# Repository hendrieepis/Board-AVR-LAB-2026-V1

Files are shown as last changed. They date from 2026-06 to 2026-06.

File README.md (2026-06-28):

# 📋 Panduan Desain: Shield Arduino Mega 2560 — PENS Expansion Board V2.0

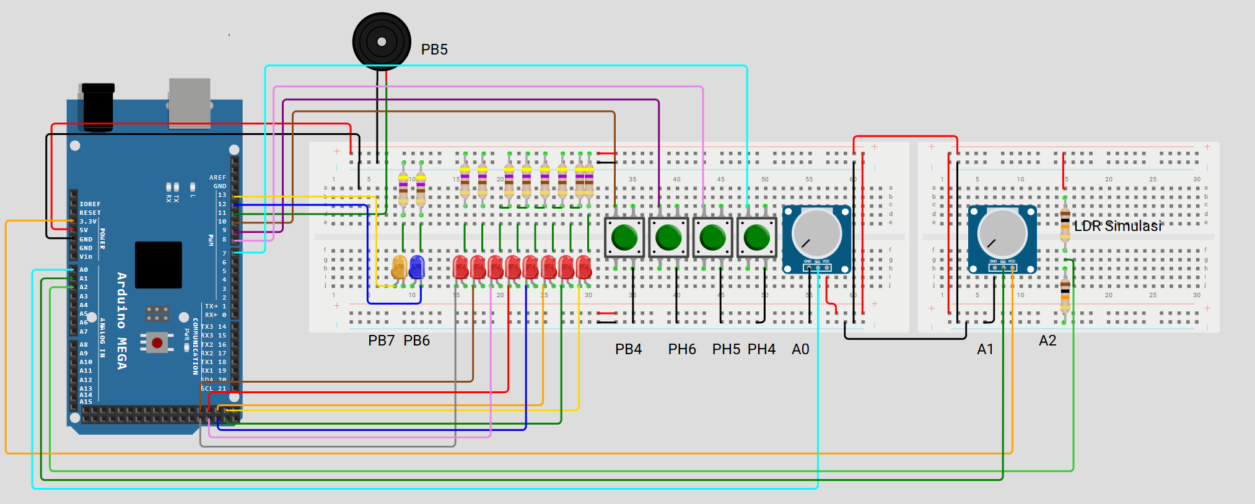
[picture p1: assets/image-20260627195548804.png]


---

## 📐 Spesifikasi Teknis

### 1. Dimensi & Form Factor

| Parameter | Nilai |
|---|---|
| Panjang | 101.6 mm / 4000 mil (exact Arduino Mega R3) |
| Lebar | 53.3 mm / 2098 mil (exact Arduino Mega R3) |
| Ketebalan PCB | 1.6 mm / 63 mil (FR4) |
| Lubang mounting | 4× (diameter 3.2 mm / 126 mil) |
| Jumlah layer | 2 (dua layer) |
| Konektor ke Mega | *Stackable female header* 2.54 mm / 100 mil |

### 2. Sumber Daya

- **Source:** Arduino Mega 5V rail saja (tidak ada *external power*)
- **Decoupling:** 4× 100 nF (0805) — distribusi dekat cluster MOSFET untuk menjaga stabilitas switching

### 3. Pin Assignment (WAJIB SAMA DENGAN WOKWI)

> ⚠️ **PENTING:** Pin *assignment* harus persis sama dengan simulator Wokwi PENS Elka. Jangan merubah *mapping* pin karena akan menyebabkan kode tidak kompatibel antara simulator dan *hardware* fisik.

#### 3.1. LED Array (8 LED Merah — PORTA)

| Arduino Pin | AVR Port | Device | Warna | Reference |
|---|---|---|---|---|
| D22 | PA0 | LED1 | Merah | D0 |
| D23 | PA1 | LED8 | Merah | D1 |
| D24 | PA2 | LED7 | Merah | D2 |
| D25 | PA3 | LED5 | Merah | D3 |
| D26 | PA4 | LED3 | Merah | D4 |
| D27 | PA5 | LED6 | Merah | D5 |
| D28 | PA6 | LED4 | Merah | D6 |
| D29 | PA7 | LED2 | Merah | D7 |

**Package:** LED SMD 0805 (`LED_SMD:LED_0805_2012Metric_Pad1.15x1.40mm_HandSolder`)

**Tata letak PCB:** Susun LED dalam satu baris dari PA0 di kiri hingga PA7 di kanan agar mahasiswa bisa membaca *pattern* `PORTA` secara visual.

#### 3.2. LED Indikator (2 LED)

| Arduino Pin | AVR Port | Device | Warna | Reference |
|---|---|---|---|---|
| D12 | PB6 | LED9 | Merah | DA1 |
| D13 | PB7 | LED10 | Hijau | DB1 |

**Package:** LED SMD 0805 (sama dengan LED array)

#### 3.3. Buzzer

| Arduino Pin | AVR Port | Device | Reference |
|---|---|---|---|
| D11 | PB5 | Buzzer (piezo/magnetic 5V) | BZ1 |

**Skema rangkaian:**

```
        +5V
         │
       ┌─┴─┐
     1 │ + │ BZ1
       │   │ Buzzer
     2 │   │
       └─┬─┘
         │
       ┌─┴─┐
       │R6 │ 1K
       └─┬─┘
         │ 3
   D11 1 ┤├─┐
    ●────┤  │ Q2
    │    ┤├─┘ BSS138
  ┌─┴─┐    │ 2
  │R5 │    │
  │1M │    │
  └─┬─┘    │
    │      │
   GND    GND
```

#### 3.4. Push Button (Active-LOW, 4 unit)

| Arduino Pin | AVR Port | Device | Reference |
|---|---|---|---|
| D10 | PB4 | BTN1 | SW1 |
| D9 | PH6 | BTN2 | SW2 |
| D8 | PH5 | BTN3 | SW3 |
| D7 | PH4 | BTN4 | SW4 |

**Skema rangkaian (debounce):**

```
   +5V
    │
  ┌─┴─┐
  │R13│ 10K
  └─┬─┘
    ●──── D7
  ┌─┴─┐
  │R14│ 1K
  └─┬─┘
    ●─────────┐
   o│         │
   SW4       ─┴─ C4
   SW_Push   ─┬─ 0.1uF
   o│         │
    ●─────────┘
    │
   GND
```

- **Package:** Tactile switch 6×6 mm THT (`Button_Switch_THT:SW_PUSH_6mm`)
- **Tinggi actuator:** Rekomendasi 7.3H (ergonomis untuk jari, tidak mudah rusak)
- Tombol aktif saat ditekan (menghubungkan pin ke GND)
- Menggunakan internal pull-up AVR (`INPUT_PULLUP` di kode) — tidak perlu resistor pull-up eksternal
- **Alasan pilih THT (bukan SMD):** Untuk praktikum mahasiswa, THT jauh lebih robust terhadap tekanan berulang dan perlakuan kasar. Jalur PCB tidak mudah rusak karena kaki pin masuk ke PTH (plated through-hole), bukan hanya solder di permukaan.

#### 3.5. Potensiometer & LDR (Input Analog)

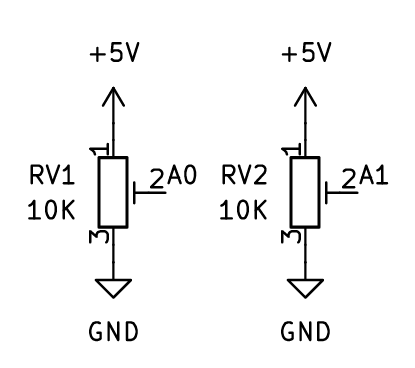
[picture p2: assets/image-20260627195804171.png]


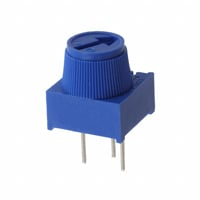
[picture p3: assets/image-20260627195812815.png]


| Arduino Pin | ADC Channel | Device | Reference | Tipe |
|---|---|---|---|---|
| A0 | ADC0 | POT1 | RV1 | Trimpot 10K |
| A1 | ADC1 | POT2 | RV2 | Trimpot 10K |
| A2 | ADC2 | LDR | R14 | GL5528 (5mm) |

**Package:**

- **Trimpot:** `Potentiometer_THT:Potentiometer_Bourns_3386P_Vertical` (Bourns 3386P 10K)
- **LDR:** `OptoDevice:R_LDR_5.1x4.3mm_P3.4mm_Vertical` (GL5528, pitch 3.4mm)

**Konfigurasi:**

- **Trimpot (RV1, RV2):** Voltage divider standar — Pin 1 ke +5V, Pin 3 ke GND, wiper (Pin 2) ke ADC
- **LDR (R14):** Voltage divider dengan resistor partner 10K (R_LDR ke +5V, R_10K ke GND, tap ke ADC)

---

## 🔌 Rangkaian Driver (MOSFET Isolation)

### Skema Driver LED (diulang untuk 8 LED PORTA + 2 LED indikator + Buzzer = 11 channel)

```
        +5V
         │
        ─┴─
        \ / D7
        ─┬─ LED
         │
       ┌─┴─┐
       │R32│ 1K
       └─┬─┘
         │ 3
  D29  1 ┤├─┐
   ●─────┤  │ Q12
   │     ┤├─┘ BSS138
 ┌─┴─┐     │ 2
 │R31│     │
 │1M │     │
 └─┬─┘     │
   │       │
  GND     GND
```

### Komponen per Channel LED

| # | Komponen | Nilai | Package | Fungsi |
|---|---|---|---|---|
| 1 | MOSFET | BSS138 | SOT-23 | Switch utama |
| 2 | Resistor pull-up | 10 kΩ | 0805 | Gate bias ke +5V |
| 3 | Resistor pull-down | 1 MΩ | 0805 | Cegah *flicker* saat pin INPUT |
| 4 | Resistor LED | 1 kΩ | 0805 | Pembatas arus LED (~3 mA) |
| 5 | LED | Merah/Hijau | 0805 | Indikator visual |

### Perilaku Driver

| Kondisi Pin Arduino | Gate MOSFET | LED |
|---|---|---|
| HIGH (5V) | HIGH | ON |
| LOW (0V) | LOW | OFF |
| INPUT (floating) | LOW (via R 1M) | OFF (tidak *flicker*) |

---

## 🔗 Antarmuka Komunikasi

### 1. Header I2C (JST PH 2.0, 4-pin)

**Reference:** J10 (atau salah satu dari J10, J11, J12)
**Footprint:** `Connector_JST:JST_PH_B4B-PH-K_1x04_P2.00mm_Vertical`

| Pin | Nama | Koneksi |
|---|---|---|
| 1 | GND | GND |
| 2 | VCC | +5V |
| 3 | SDA | Arduino pin 20 |
| 4 | SCL | Arduino pin 21 |

> **Catatan I2C pull-up:** ATmega2560 memiliki internal pull-up untuk SDA/SCL. Untuk modul I2C 5V standard (OLED, sensor), internal pull-up cukup. Jika menggunakan modul yang butuh pull-up eksternal, tambahkan resistor 4.7K di sisi modul.

### 2. Header SPI (JST PH 2.0, 6-pin)

**Reference:** J8 atau J9
**Footprint:** `Connector_JST:JST_PH_B6B-PH-K_1x06_P2.00mm_Vertical`

| Pin | Nama | Koneksi |
|---|---|---|
| 1 | GND | GND |
| 2 | VCC | +5V |
| 3 | MOSI | Arduino pin 51 |
| 4 | MISO | Arduino pin 50 |
| 5 | SCK | Arduino pin 52 |
| 6 | CS | Arduino pin 53 |

### 3. Header UART (JST PH 2.0, 4-pin)

**Reference:** J11 atau J12
**Footprint:** `Connector_JST:JST_PH_B4B-PH-K_1x04_P2.00mm_Vertical`

| Pin | Nama | Koneksi |
|---|---|---|
| 1 | GND | GND |
| 2 | VCC | +5V |
| 3 | TX1 | Arduino pin 18 (Serial1 TX) |
| 4 | RX1 | Arduino pin 19 (Serial1 RX) |

> Menggunakan **Serial1** (bukan Serial0) agar USB *debug* tetap tersedia untuk *Serial Monitor*.

**Praktik desain:**

- *Expose* semua pin yang digunakan di sisi atas dan bawah *board*
- *Silkscreen* dual label: "D22 / PA0", "A0 / ADC0", dst.
- Termasuk multiple *access point* untuk +5V dan GND

---

## 🎨 Prioritas Layout PCB

1. LED array disusun horizontal dari kiri ke kanan: PA0 → PA7
2. Push button dikelompokkan (4 tombol dalam satu baris)
3. Input analog dikelompokkan (2 trimpot + 1 LDR dalam satu area)
4. Connector JST di tepi *board* untuk akses kabel yang mudah
5. Silkscreen dual label (Arduino pin + AVR port) pada setiap pin *breakout*
6. Component reference (R1, C1, Q1, dll.) terlihat setelah *assembly*
7. **LDR penempatan:** Jauhkan minimal 20mm dari LED indikator untuk menghindari cross-talk cahaya

---

## 🏭 Spesifikasi PCB & Manufacturing

### Spesifikasi Fisik

| Parameter | Nilai |
|---|---|
| Layer | 2 |
| Material | FR4 1.6 mm |
| Copper weight | 1 oz (35 µm) |
| *Soldermask* | Hitam atau ungu |
| *Silkscreen* | Putih |
| Surface finish | HASL Lead-free (gratis) |
| *Ground plane* | *Bottom layer* |
| *Top layer* | Signal + komponen |

### Layer Strategy

```
TOP layer:    Body semua komponen (SMD & THT)
              SMD solder pads di sini
              Signal trace + VCC

BOTTOM layer: Solder pad untuk pin THT (saja)
              Ground plane solid
              Minimize signal trace
```

**Prinsip desain:**

- ❌ Bottom layer **JANGAN** dijadikan VCC plane
- ✅ Bottom layer = **Ground plane solid** (lebih baik untuk EMI, signal integrity, dan ADC accuracy)
- ✅ VCC sebagai **trace tebal** di top layer (0.5 mm / 20 mil)
- ✅ Decoupling capacitor (100 nF) dekat dengan cluster MOSFET
- ✅ Stitching via di area ground pour (1 via per 1–2 cm²) untuk low-impedance ground

### Bonus

**Bonus (optional, nilai plus):** Tambahkan **logo PENS** dan/atau **tulisan "Prodi Elka"** di area kosong **Bottom Silkscreen (B.Silkscreen)** sebagai identitas board. Bisa dalam bentuk:

- Logo PENS (import image ke KiCad)
- Tulisan "Prodi Elka - PENS" dengan KiCad text tool
- Atau kombinasi keduanya

Contoh:

```
┌────────────────────────────────────┐
│                                    │
│           [Logo PENS]              │
│                                    │
│        PENS EXPANSION BOARD        │
│           V2.0 (2026)              │
│      Prodi Teknik Elektronika      │
│                                    │
└────────────────────────────────────┘
```

---

## 📏 Design Rules untuk JLCPCB (Safe Settings)

> ⚠️ **PENTING:** Design rules di bawah ini adalah **recommended safe values** — lebih besar dari JLCPCB minimum — untuk margin terhadap manufacturing tolerance. Jangan mendesain persis di JLCPCB minimum karena risiko reject atau defect tinggi.

### Design Rules Cheatsheet

```
┌──────────────────────────────────────────────────────┐
│  PCB DESIGN RULES (JLCPCB Safe Settings)             │
├──────────────────────────────────────────────────────┤
│                                                      │
│  TRACK WIDTH:                                        │
│    Signal:  0.25 mm  (10 mil)                        │
│    Power:   0.5  mm  (20 mil)                        │
│                                                      │
│  CLEARANCE:                                          │
│    Track – track:  0.2 mm  (8 mil)                   │
│    Track – pad:    0.2 mm  (8 mil)                   │
│    Track – edge:   0.3 mm  (12 mil)                  │
│                                                      │
│  VIA:                                                │
│    Signal:  0.3 / 0.6 mm  (12 / 24 mil)              │
│    Power:   0.4 / 0.8 mm  (16 / 32 mil)              │
│                                                      │
│  HOLE (THT):                                         │
│    Min drill:     0.3 mm  (12 mil) – JLCPCB limit    │
│    Typical pin:   0.6 – 1.0 mm  (24 – 39 mil)        │
│    Annular ring:  0.15 mm  (6 mil) per side          │
│                                                      │
│  BOARD EDGE:                                         │
│    Copper – edge:     0.3 mm  (12 mil)               │
│    Component – edge:  1.0 mm  (39 mil)               │
│    Mounting – edge:   2.0 mm  (79 mil)               │
│                                                      │
│  SILKSCREEN:                                         │
│    Line width:   0.15 mm  (6 mil)                    │
│    Text height:  1.0 mm  (39 mil)                    │
│    Pad clear:    0.15 mm  (6 mil)                    │
│                                                      │
│  UNIT CONVERSION:                                    │
│    1 mil = 0.0254 mm                                 │
│    1 mm  = 39.37 mil                                 │
│                                                      │
└──────────────────────────────────────────────────────┘
```

> 💡 **Tip praktis:** Biasakan mikir dalam mil untuk track width dan mm untuk board dimension — convention yang umum di komunitas PCB global. KiCad support keduanya, switch via View → Units atau shortcut Ctrl+U.

**Current capacity:** Trace 0.5 mm (20 mil) pada 1 oz copper = ~1.6 A (10°C rise). Estimasi beban project ini ≈ 300 mA (10 LED × 3 mA + buzzer 50 mA + modul external 200 mA), jadi margin ~5× — sangat aman.

### Clearance Komponen

**Clearance** = jarak minimum antara dua komponen di PCB, diukur dari body/pad komponen satu ke body/pad komponen sebelahnya.

```
[Komponen A] ←─── clearance ───→ [Komponen B]
   body                              body
```

| Antar Komponen | Recommended | Alasan |
|---|---|---|
| SMD 0805 – SMD 0805 | **0.5 mm (20 mil)** | Akses solder iron |
| BSS138 (SOT-23) – neighbor | **1.0 mm (39 mil)** | Akses untuk rework |
| LED 0805 – LED 0805 (array PORTA) | **1.0 mm (39 mil)** | Visual separation, tidak overlap cahaya |
| Tactile switch (THT) – neighbor | **3 mm (118 mil)** | Space untuk jari menekan |
| Trimpot 3386P – neighbor | **2 mm (79 mil)** | Akses obeng untuk adjust |
| **LDR – LED indikator** | **20–30 mm (787–1181 mil)** | Hindari cross-talk cahaya ke LDR |
| JST PH – tepi PCB | **5 mm (197 mil)** | Clearance kabel saat dicolok |

> Ini berbeda dengan trace clearance (jarak antar jalur tembaga). Clearance komponen lebih ke urusan fisik/mekanis, sedangkan trace clearance urusan elektris.

### Cara Set di KiCad

1. PCB Editor → **File → Board Setup**
2. Tab **Design Rules → Constraints** → input nilai Global Constraints
3. Tab **Design Rules → Net Classes** → tambahkan class "Power", assign net VCC dan GND
4. Save

**Verifikasi sebelum export:** Inspect → **Design Rules Checker (DRC)** → target **zero error**, warning silkscreen diperiksa manual.

---

## ✅ Checklist Sebelum Submit Gerber

### Phase 1: KiCad DRC

- [ ] DRC run dengan zero error
- [ ] Warning silkscreen sudah direview (silkscreen overlap pad akan auto-remove oleh JLCPCB)
- [ ] Tidak ada unconnected net

### Phase 2: Visual Review

- [ ] **3D View** (Alt+3) — semua komponen muncul & positioned benar
- [ ] **Ground plane** di bottom layer solid, tidak split oleh signal
- [ ] **Stitching via** di ground pour, kerapatan 1 per 1–2 cm²
- [ ] **Decoupling cap** (100 nF) dekat dengan cluster MOSFET
- [ ] **Silkscreen** label Arduino pin + AVR port readable
- [ ] **Reference designator** (R1, Q1, dll.) visible setelah assembly

### Phase 3: Mechanical Fit

- [ ] **Board outline** (Edge.Cuts) closed polygon, 101.6 × 53.3 mm
- [ ] **4 mounting hole** di lokasi exact Arduino Mega R3
- [ ] **Stackable pin header** align dengan Arduino Mega socket
- [ ] **Clearance barrel jack** + **USB connector** Mega
- [ ] Tinggi komponen < 15 mm (agar shield bisa di-stack)

### Phase 4: Print 1:1 Test

- [ ] Print PDF top + bottom layer 1:1 di kertas
- [ ] Verifikasi skala dengan penggaris
- [ ] Taruh komponen fisik di atas print
- [ ] Footprint match pad, orientasi benar
- [ ] Komponen THT tidak bentrok dengan komponen SMD sekitar

### Phase 5: Gerber Export & Review

- [ ] File → **Fabrication Outputs → Gerbers** → export semua layer
- [ ] **Generate drill files** (.drl) — centang!
- [ ] Upload zip ke **JLCPCB Gerber Viewer** (online)
- [ ] Visual inspection setiap layer (top copper, bottom copper, silkscreen, drill)
- [ ] Verifikasi board size di viewer

### Common Rejection Reasons dari JLCPCB

| Masalah | Solusi |
|---|---|
| Trace terlalu kecil (<6 mil) | Set min track width 0.2 mm (8 mil) |
| Hole <0.3 mm (12 mil) | Min drill 0.3 mm (12 mil) untuk via, 0.6 mm (24 mil) untuk pin THT |
| Trace terlalu dekat ke tepi PCB | Edge clearance minimum 0.3 mm (12 mil) — safer 0.5 mm (20 mil) |
| Silkscreen overlap pad | Kasih gap 0.15 mm (6 mil) (atau ikhlaskan auto-remove) |
| Missing drill file | Export .drl terpisah saat Gerber export |
| Board outline tidak closed | Edge.Cuts harus single closed polygon |

---

## 💪 Pro Tips dari Pengalaman Fabrikasi

### 1. Mulai DRC Lenient, Tighten Later

Saat awal routing, set DRC minimum (0.127 mm) biar KiCad router fleksibel. Setelah semua trace selesai, **tighten DRC** ke nilai recommended (0.2 mm) lalu re-run DRC. Fix error yang muncul satu per satu.

### 2. Jangan Mepet Manufacturing Minimum

JLCPCB minimum 0.127 mm, tapi desain di 0.2 mm. Manufacturing punya tolerance ±0.05 mm, kalau mepet minimum → kena tolerance minus → fail. Selalu kasih margin.

### 3. Test Points untuk Debugging

Tambahkan **test points** (pad TH 1 mm diameter) di signal kritikal untuk kemudahan debugging pasca-assembly:

| Signal | Lokasi Recommended |
|---|---|
| VCC 5V | Dekat power input header |
| GND | Multiple (minimum 3 lokasi di PCB) |
| Analog A0–A2 | Dekat trimpot/LDR |
| UART TX/RX | Dekat JST PH UART |
| SPI bus | Dekat JST PH SPI |
| Gate MOSFET | 1–2 channel sebagai sample (untuk scope) |

**Footprint:** `TestPoint:TestPoint_Pad_D1.5mm` atau `TestPoint_THTPad_1.0x1.0mm_Drill0.5mm`

### 4. Print 1:1 Manual Check

Sebelum klik "Submit" di JLCPCB:

1. Export PDF top + bottom layer dengan scale **1:1**
2. Print di kertas, verifikasi skala dengan penggaris (pastikan PCB 101.6 mm sesuai penggaris)
3. Taruh komponen fisik di atas cetakan
4. Cek alignment footprint, clearance, orientasi
5. Simulasi: tekan tombol, putar trimpot, colok JST — apakah ada yang bentrok?

**10 menit manual check = save $10 wasted PCB + 2 minggu waiting.**

### 5. Save Gerber sebagai "Release"

Setelah submit, **tag Gerber file** dengan versi (misal `ExpansionBoard-V1.0-Gerber.zip`) dan commit ke Git. Kalau nanti ada revisi, bisa compare version history.

---

## 📚 Referensi & Resources

### Datasheet Komponen Kritis

- BSS138 MOSFET Datasheet
- ATmega2560 (Arduino Mega) Datasheet
- JST PH Series Datasheet
- Bourns 3386P Potentiometer Datasheet
- LDR GL5528 Datasheet

### Tutorial & Learning

- KiCad Getting Started
- JLCPCB Ordering Guide

### Inspirasi Desain

- Cytron Maker Pi Pico Schematic — referensi MOSFET isolation topology
- Arduino Mega R3 Schematic

### Library KiCad

- SnapEDA Arduino Mega 2560 Rev3

## Release

VersiA

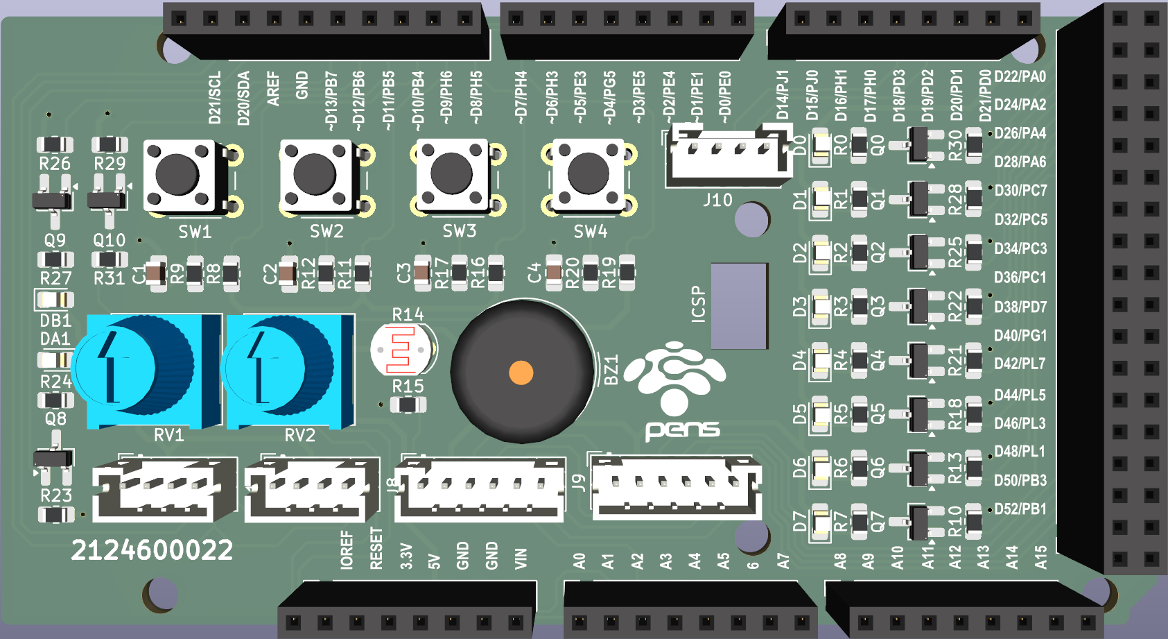
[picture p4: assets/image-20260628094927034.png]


- KICAD ->    [versiA](versiA) 

- Gerver->  https://github.com/hendrieepis/Board-AVR-LAB-2026-V1/blob/master/versiA/gerber.zip

VersiB

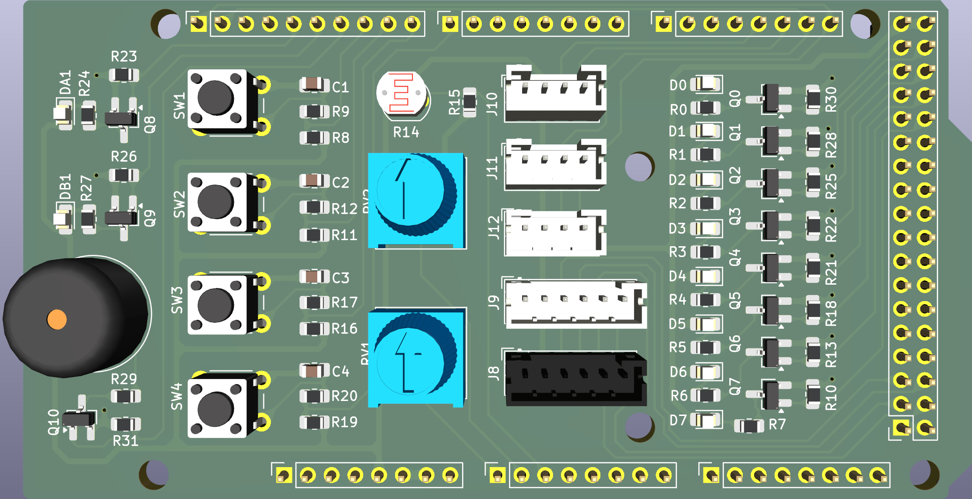
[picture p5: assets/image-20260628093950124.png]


- KICAD ->     [VersiB](VersiB) 

- Gerber ->   https://github.com/hendrieepis/Board-AVR-LAB-2026-V1/blob/master/VersiB/gerber.zip

Pcloud

- https://e.pcloud.link/publink/show?code=kZzxKcZidlPBQnEcohYrJGMhkQTauFlQ4nX

## Test hardware

-  [test-hardware](test-hardware)

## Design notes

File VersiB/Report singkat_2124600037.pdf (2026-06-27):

NAMA : MUHAHAMMAD BAGUS EKA WIJAYA KELAS: 2 D4 EB
NRP :2124600037

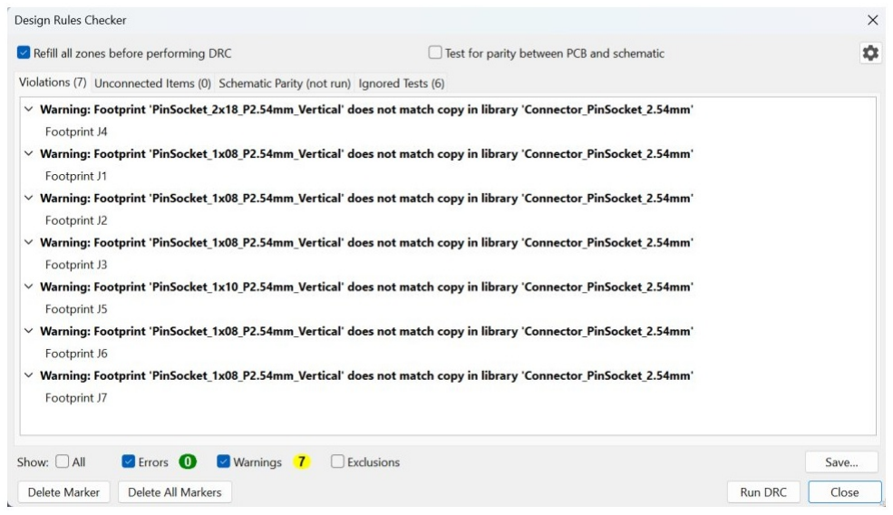
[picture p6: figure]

Sering masuk Properties saat melakukan routing, solusinya routing pelan pelan . ·Pertama kali menggunakan Kicad jadi bingung untuk letak setting dan short cut fiturnya .Solusinya di bantu dengan Al dan YouTube.
·Jumlah Via yang di gunakan 11 Via.

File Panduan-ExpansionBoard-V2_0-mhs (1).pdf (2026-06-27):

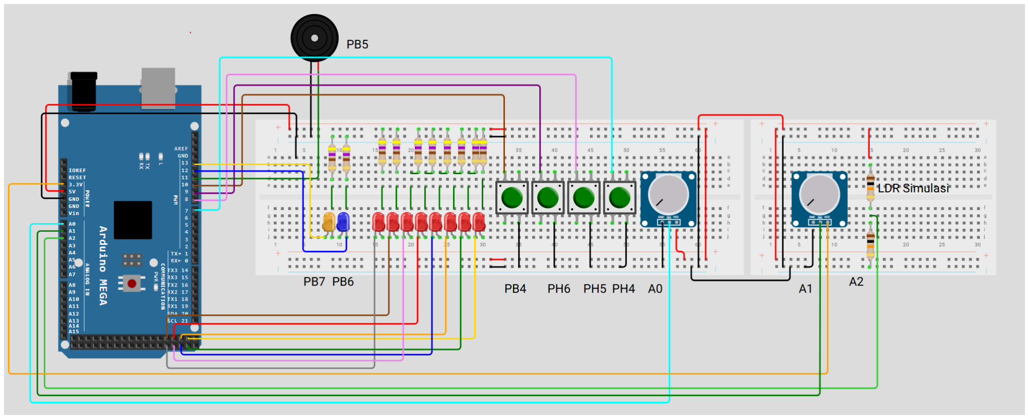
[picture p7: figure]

Parameter | Nilai
Panjang | 101.6 mm / 4000 mil (exact Arduino Mega R3)
Lebar | 53.3 mm / 2098 mil (exact Arduino Mega R3)
Ketebalan PCB | 1.6 mm / 63 mil (FR4)
Lubang mounting | 4× (diameter 3.2 mm / 126 mil)
Jumlah layer | 2 (dua layer)
Konektor ke Mega | Stackable female header 2.54 mm / 100 mil
Arduino Pin | AVR Port | Device | Warna | Reference
D22 | PA0 | LED1 | Merah | D0

# 📋 Panduan Desain: Shield Arduino Mega 2560 — PENS Expansion Board V2.0

# 📐 Spesifikasi Teknis

## 1. Dimensi & Form Factor

## 2. Sumber Daya

Source: Arduino Mega 5V rail saja (tidak ada external power)
Decoupling: 4× 100 nF (0805) — distribusi dekat cluster MOSFET untuk menjaga stabilitas switching

## 3. Pin Assignment (WAJIB SAMA DENGAN WOKWI)

⚠️ PENTING: Pin assignment harus persis sama dengan simulator Wokwi PENS Elka. Jangan merubah mapping pin karena akan menyebabkan kode tidak kompatibel antara simulator dan hardware fisik.

### 3.1. LED Array (8 LED Merah — PORTA)

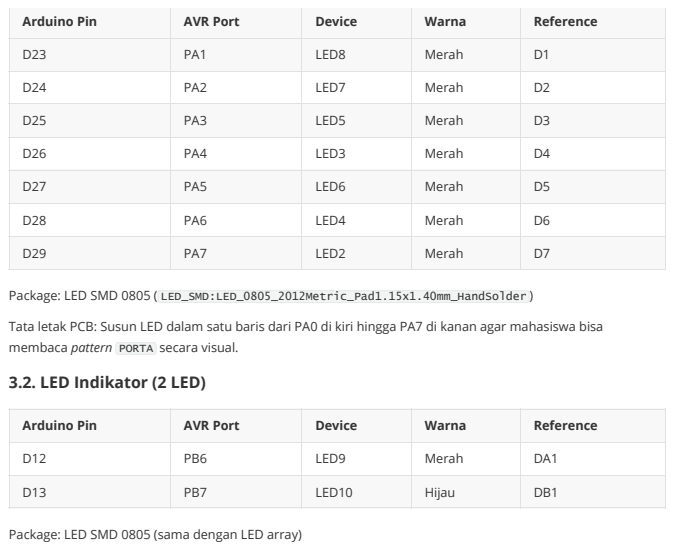
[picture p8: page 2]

Arduino Pin | AVR Port | Device | Warna | Reference

D23 | PA1 | LED8 | Merah | D1

D24 | PA2 | LED7 | Merah | D2

D25 | PA3 | LED5 | Merah | D3

D26 | PA4 | LED3 | Merah | D4

D27 | PA5 | LED6 | Merah | D5

D28 | PA6 | LED4 | Merah | D6

D29 | PA7 | LED2 | Merah | D7

Package: LED SMD 0805 ( LED_SMD:LED_0805_2012Metric_Pad1.15x1.40mm_HandSolder )
Tata letak PCB: Susun LED dalam satu baris dari PA0 di kiri hingga PA7 di kanan agar mahasiswa bisa
membaca pattern PORTA secara visual.
3.2. LED Indikator (2 LED)

D12 | PB6 | LED9 | Merah | DA1

D13 | PB7 | LED10 | Hijau | DB1

Package: LED SMD 0805 (sama dengan LED array)

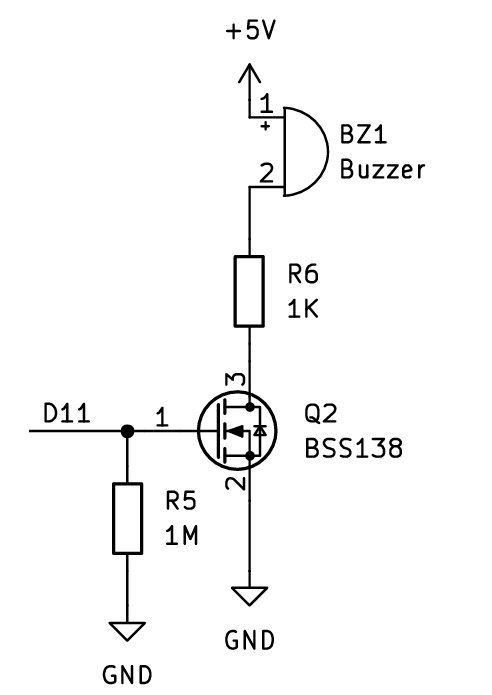
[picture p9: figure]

Arduino Pin | AVR Port | Device | Reference
D11 | PB5 | Buzzer (piezo/magnetic 5V) | BZ1

### 3.3. Buzzer

### 3.4. Push Button (Active-LOW, 4 unit)

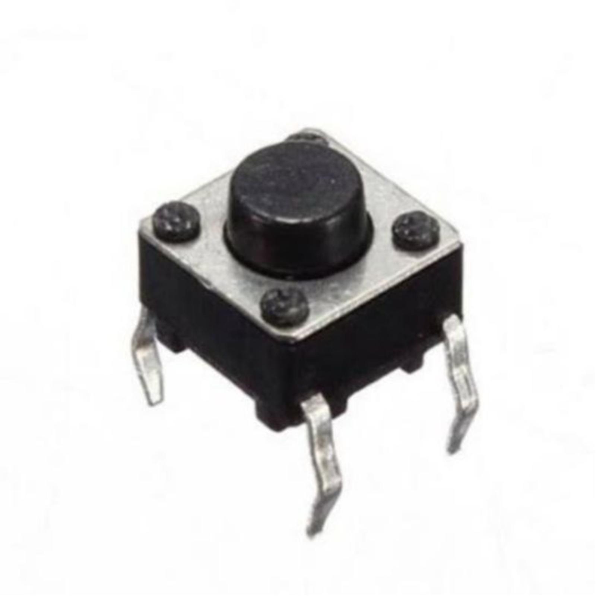
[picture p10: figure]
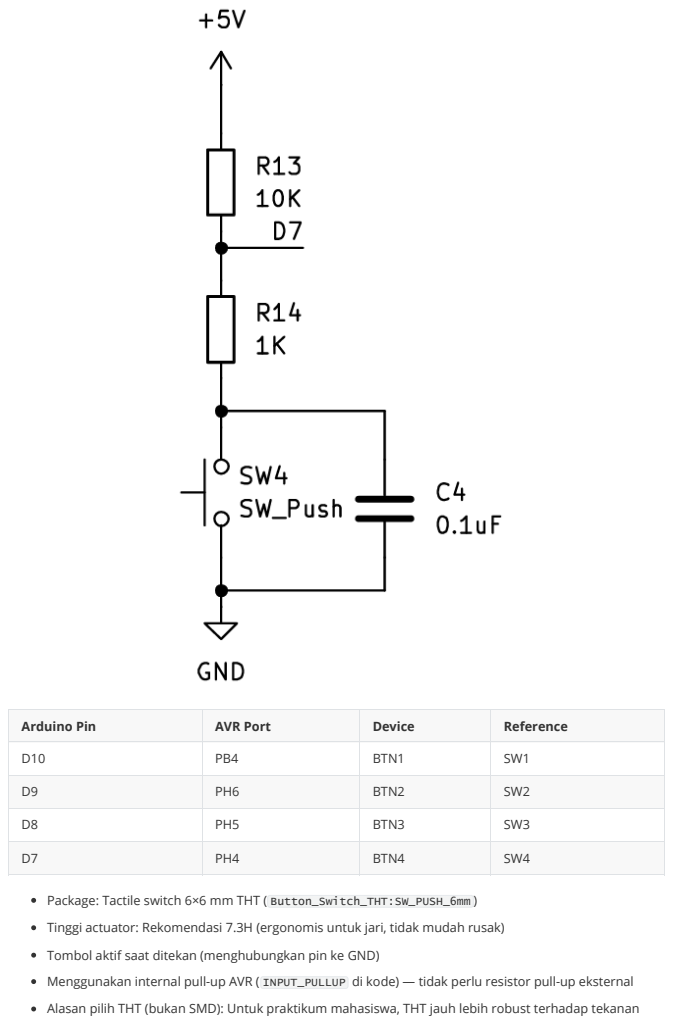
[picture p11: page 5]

Arduino Pin | AVR Port | Device | Reference

D10 | PB4 | BTN1 | SW1

D9 | PH6 | BTN2 | SW2

D8 | PH5 | BTN3 | SW3

D7 | PH4 | BTN4 | SW4

Package: Tactile switch 6×6 mm THT ( Button_Switch_THT:SW_PUSH_6mm )
Tinggi actuator: Rekomendasi 7.3H (ergonomis untuk jari, tidak mudah rusak)
Tombol aktif saat ditekan (menghubungkan pin ke GND)
Menggunakan internal pull-up AVR ( INPUT_PULLUP di kode) — tidak perlu resistor pull-up eksternal
Alasan pilih THT (bukan SMD): Untuk praktikum mahasiswa, THT jauh lebih robust terhadap tekanan

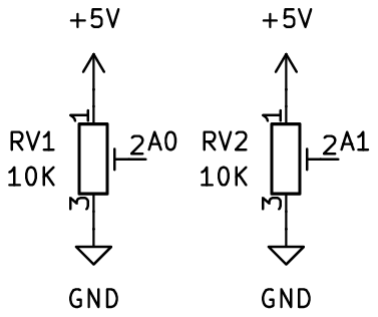
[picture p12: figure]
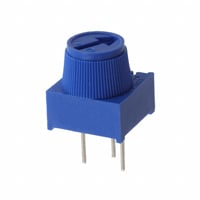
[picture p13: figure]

Arduino Pin | ADC Channel | Device | Reference | Tipe
A0 | ADC0 | POT1 | RV1 | Trimpot 10K
A1 | ADC1 | POT2 | RV2 | Trimpot 10K
A2 | ADC2 | LDR | R14 | GL5528 (5mm)

berulang dan perlakuan kasar. Jalur PCB tidak mudah rusak karena kaki pin masuk ke PTH (plated through-hole), bukan hanya solder di permukaan

### 3.5. Potensiometer & LDR (Input Analog)

Package:

Trimpot: Potentiometer_THT:Potentiometer_Bourns_3386P_Vertical (Bourns 3386P 10K)

LDR: OptoDevice:R_LDR_5.1x4.3mm_P3.4mm_Vertical (GL5528, pitch 3.4mm)

Konfigurasi:

Trimpot (RV1, RV2): Voltage divider standar — Pin 1 ke +5V, Pin 3 ke GND, wiper (Pin 2) ke ADC LDR (R14): Voltage divider dengan resistor partner 10K (R_LDR ke +5V, R_10K ke GND, tap ke ADC)

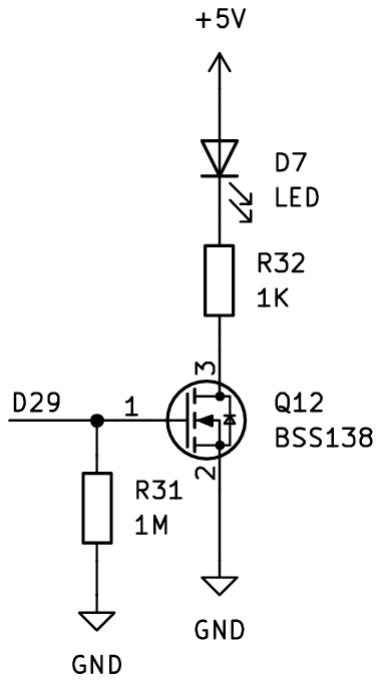
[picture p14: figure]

# | Komponen | Nilai | Package | Fungsi

1 | MOSFET | BSS138 | SOT-23 | Switch utama
2 | Resistor pull-up | 10 kΩ | 0805 | Gate bias ke +5V
3 | Resistor pull-down | 1 MΩ | 0805 | Cegah flicker saat pin INPUT
4 | Resistor LED | 1 kΩ | 0805 | Pembatas arus LED (~3 mA)
5 | LED | Merah/Hijau | 0805 | Indikator visual

# 🔌 Rangkaian Driver (MOSFET Isolation)

## Skema Driver LED (diulang untuk 8 LED PORTA + 2 LED indikator + Buzzer = 11 channel)

## Komponen per Channel LED

Kondisi Pin Arduino | Gate MOSFET | LED
HIGH (5V) | HIGH | ON
LOW (0V) | LOW | OFF
INPUT (floating) | LOW (via R 1M) | OFF (tidak flicker)
Pin | Nama | Koneksi
1 | GND | GND
2 | VCC | +5V
3 | SDA | Arduino pin 20
4 | SCL | Arduino pin 21
Pin | Nama | Koneksi
1 | GND | GND
2 | VCC | +5V
3 | MOSI | Arduino pin 51
4 | MISO | Arduino pin 50
5 | SCK | Arduino pin 52
6 | CS | Arduino pin 53

## Perilaku Driver

# 🔗 Antarmuka Komunikasi

1. Header I2C (JST PH 2.0, 4-pin)

Reference: J10 (atau salah satu dari J10, J11, J12)

Footprint: Connector_JST:JST_PH_B4B-PH-K_1x04_P2.00mm_Vertical

Catatan I2C pull-up: ATmega2560 memiliki internal pull-up untuk SDA/SCL. Untuk modul I2C 5V standard (OLED, sensor), internal pull-up cukup. Jika menggunakan modul yang butuh pull-up eksternal, tambahkan resistor 4.7K di sisi modul.

## 2. Header SPI (JST PH 2.0, 6-pin)

Reference: J8 atau J9
Footprint: Connector_JST:JST_PH_B6B-PH-K_1x06_P2.00mm_Vertical

Pin | Nama | Koneksi
1 | GND | GND
2 | VCC | +5V
3 | TX1 | Arduino pin 18 (Serial1 TX)
4 | RX1 | Arduino pin 19 (Serial1 RX)
Parameter | Nilai
Layer | 2
Material | FR4 1.6 mm
Copper weight | 1 oz (35 µm)
Soldermask | Hitam atau ungu
Silkscreen | Putih
Surface finish | HASL Lead-free (gratis)

## 3. Header UART (JST PH 2.0, 4-pin)

Reference: J11 atau J12

Footprint: Connector_JST:JST_PH_B4B-PH-K_1x04_P2.00mm_Vertical

Menggunakan Serial1 (bukan Serial0) agar USB debug tetap tersedia untuk Serial Monitor. Praktik desain:

Expose semua pin yang digunakan di sisi atas dan bawah board
Silkscreen dual label: "D22 / PA0", "A0 / ADC0", dst.
Termasuk multiple access point untuk +5V dan GND

# 🎨 Prioritas Layout PCB

1. LED array disusun horizontal dari kiri ke kanan: PA0 → PA7
2. Push button dikelompokkan (4 tombol dalam satu baris)
3. Input analog dikelompokkan (2 trimpot + 1 LDR dalam satu area)
4. Connector JST di tepi board untuk akses kabel yang mudah
5. Silkscreen dual label (Arduino pin + AVR port) pada setiap pin breakout
6. Component reference (R1, C1, Q1, dll.) terlihat setelah assembly
7. LDR penempatan: Jauhkan minimal 20mm dari LED indikator untuk menghindari cross-talk cahaya

# 🏭 Spesifikasi PCB & Manufacturing

## Spesifikasi Fisik

Parameter | Nilai
Ground plane | Bottom layer
Top layer | Signal + komponen

## Layer Strategy

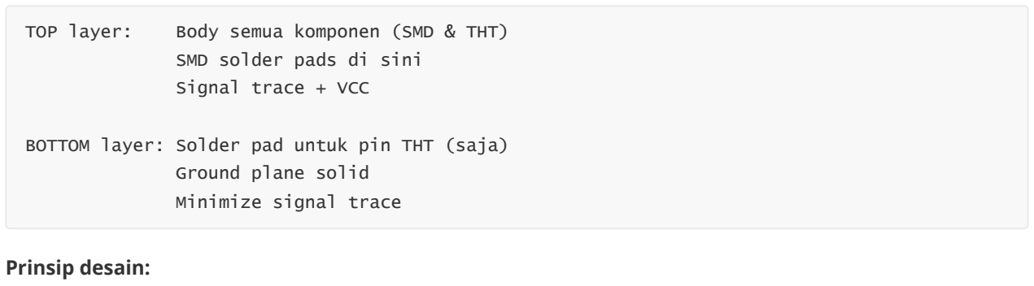
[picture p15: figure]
Prinsip desain:; SMD solder pads di sini; Signal trace + VCC; Ground plane solid; Minimize signal trace

❌ Bottom layer JANGAN dijadikan VCC plane
✅ Bottom layer = Ground plane solid (lebih baik untuk EMI, signal integrity, dan ADC accuracy) ✅ VCC sebagai trace tebal di top layer (0.5 mm / 20 mil)
✅ Decoupling capacitor (100 nF) dekat dengan cluster MOSFET
✅ Stitching via di area ground pour (1 via per 1–2 cm²) untuk low-impedance ground

## Bonus

Bonus (optional, nilai plus): - Tambahkan logo PENS dan/atau tulisan "Prodi Elka" di area kosong Bottom Silkscreen (B.Silkscreen) sebagai identitas board. Bisa dalam bentuk: - Logo PENS (import image ke KiCad) - Tulisan "Prodi Elka - PENS" dengan KiCad text tool - Atau kombinasi keduanya. Contoh

# 📏 Design Rules untuk JLCPCB (Safe Settings)

⚠️ PENTING: Design rules di bawah ini adalah recommended safe values — lebih besar dari JLCPCB minimum — untuk margin terhadap manufacturing tolerance. Jangan mendesain persis di JLCPCB minimum karena risiko reject atau defect tinggi.

TOP layer: Body semua komponen (SMD & THT)

BOTTOM layer: Solder pad untuk pin THT (saja)

┌────────────────────────────────────┐
│ | | │
│ | [Logo PENS] | │
│ | | │
│ | PENS EXPANSION BOARD | │
│ | V2.0 (2026) | │
│ | Prodi Teknik Elektronika | │
│ | | │
└────────────────────────────────────┘

## Design Rules Cheatsheet

💡 Tip praktis: Biasakan mikir dalam mil untuk track width dan mm untuk board dimension — convention yang umum di komunitas PCB global. KiCad support keduanya, switch via View → Units atau shortcut Ctrl+U.

Current capacity: Trace 0.5 mm (20 mil) pada 1 oz copper = ~1.6 A (10°C rise). Estimasi beban project ini ≈ 300 mA (10 LED × 3 mA + buzzer 50 mA + modul external 200 mA), jadi margin ~5× — sangat aman.

## Clearance Komponen

Clearance = jarak minimum antara dua komponen di PCB, diukur dari body/pad komponen satu ke body/pad komponen sebelahnya.

┌──────────────────────────────────────────────────────┐
│ PCB DESIGN RULES (JLCPCB Safe Settings) | │
├──────────────────────────────────────────────────────┤
│ | | | | | │
│ TRACK WIDTH: | │
│ | Signal: | 0.25 mm | (10 mil) | │
│ | Power: | 0.5 | mm | (20 mil) | │
│ | | | | | │
│ CLEARANCE: | │
│ | Track – track: | 0.2 mm | (8 mil) | │
│ | Track – pad: | 0.2 mm | (8 mil) | │
│ | Track – edge: | 0.3 mm | (12 mil) | │
│ | | | | | │
│ VIA: | │
│ | Signal: | 0.3 / 0.6 mm | (12 / 24 mil) | │
│ | Power: | 0.4 / 0.8 mm | (16 / 32 mil) | │
│ | | | | | │
│ HOLE (THT): | │
│ | Min drill: | 0.3 mm | (12 mil) — JLCPCB limit | │
│ | Typical pin: | 0.6 – 1.0 mm | (24 – 39 mil) | │
│ | Annular ring: | 0.15 mm | (6 mil) per side | │
│ | | | | | │
│ BOARD EDGE: | │
│ | Copper – edge: | 0.3 mm | (12 mil) | │
│ | Component – edge: | 1.0 mm | (39 mil) | │
│ | Mounting – edge: | 2.0 mm | (79 mil) | │
│ | | | | | │
│ SILKSCREEN: | │
│ | Line width: | 0.15 mm | (6 mil) | │
│ | Text height: | 1.0 mm | (39 mil) | │
│ | Pad clear: | 0.15 mm | (6 mil) | │
│ | | | | | │
│ UNIT CONVERSION: | │
│ | 1 mil = 0.0254 mm | │
│ | 1 mm | = 39.37 mil | │
│ | | | | | │
└──────────────────────────────────────────────────────┘
[Komponen A] | ←─── clearance ───→ | [Komponen B]
body | | body

Antar Komponen | Recommended | Alasan
SMD 0805 – SMD 0805 | 0.5 mm (20 mil) | Akses solder iron
BSS138 (SOT-23) – neighbor | 1.0 mm (39 mil) | Akses untuk rework
LED 0805 – LED 0805 (array PORTA) | 1.0 mm (39 mil) | Visual separation, tidak overlap cahaya
Tactile switch (THT) – neighbor | 3 mm (118 mil) | Space untuk jari menekan
Trimpot 3386P – neighbor | 2 mm (79 mil) | Akses obeng untuk adjust
LDR – LED indikator | 20–30 mm (787–1181 mil) | Hindari cross-talk cahaya ke LDR
JST PH – tepi PCB | 5 mm (197 mil) | Clearance kabel saat dicolok

Ini berbeda dengan trace clearance (jarak antar jalur tembaga). Clearance komponen lebih ke urusan fisik/mekanis, sedangkan trace clearance urusan elektris.

## Cara Set di KiCad

1. PCB Editor → File → Board Setup
2. Tab Design Rules → Constraints → input nilai Global Constraints
3. Tab Design Rules → Net Classes → tambahkan class "Power", assign net VCC dan GND
4. Save
Verifikasi sebelum export: Inspect → Design Rules Checker (DRC) → target zero error, warning silkscreen diperiksa manual.

## Checklist Sebelum Submit Gerber

### Phase 1: KiCad DRC

DRC run dengan zero error
Warning silkscreen sudah direview (silkscreen overlap pad akan auto-remove oleh JLCPCB) Tidak ada unconnected net

### Phase 2: Visual Review

3D View (Alt+3) — semua komponen muncul & positioned benar Ground plane di bottom layer solid, tidak split oleh signal Stitching via di ground pour, kerapatan 1 per 1–2 cm² Decoupling cap (100 nF) dekat dengan cluster MOSFET Silkscreen label Arduino pin + AVR port readable Reference designator (R1, Q1, dll.) visible setelah assembly

Masalah | Solusi
Trace terlalu kecil (<6 mil) | Set min track width 0.2 mm (8 mil)
Hole <0.3 mm (12 mil) | Min drill 0.3 mm (12 mil) untuk via, 0.6 mm (24 mil) untuk pin THT
Trace terlalu dekat ke tepi PCB | Edge clearance minimum 0.3 mm (12 mil) — safer 0.5 mm (20 mil)
Silkscreen overlap pad | Kasih gap 0.15 mm (6 mil) (atau ikhlaskan auto-remove)
Missing drill file | Export .drl terpisah saat Gerber export
Board outline tidak closed | Edge.Cuts harus single closed polygon

### Phase 3: Mechanical Fit

Board outline (Edge.Cuts) closed polygon, 101.6 × 53.3 mm

### 4 mounting hole di lokasi exact Arduino Mega R3

Stackable pin header align dengan Arduino Mega socket Clearance barrel jack + USB connector Mega
Tinggi komponen < 15 mm (agar shield bisa di-stack)

### Phase 4: Print 1:1 Test

Print PDF top + bottom layer 1:1 di kertas Verifikasi skala dengan penggaris
Taruh komponen fisik di atas print
Footprint match pad, orientasi benar
Komponen THT tidak bentrok dengan komponen SMD sekitar

### Phase 5: Gerber Export & Review

File → Fabrication Outputs → Gerbers → export semua layer Generate drill files (.drl) — centang!
Upload zip ke JLCPCB Gerber Viewer (online)
Visual inspection setiap layer (top copper, bottom copper, silkscreen, drill) Verifikasi board size di viewer

## Common Rejection Reasons dari JLCPCB

## Pro Tips dari Pengalaman Fabrikasi

### 1. Mulai DRC Lenient, Tighten Later

Saat awal routing, set DRC minimum (0.127 mm) biar KiCad router fleksibel. Setelah semua trace selesai, tighten DRC ke nilai recommended (0.2 mm) lalu re-run DRC. Fix error yang muncul satu per satu.

### 2. Jangan Mepet Manufacturing Minimum

JLCPCB minimum 0.127 mm, tapi desain di 0.2 mm. Manufacturing punya tolerance ±0.05 mm, kalau mepet minimum → kena tolerance minus → fail. Selalu kasih margin.

### 3. Test Points untuk Debugging

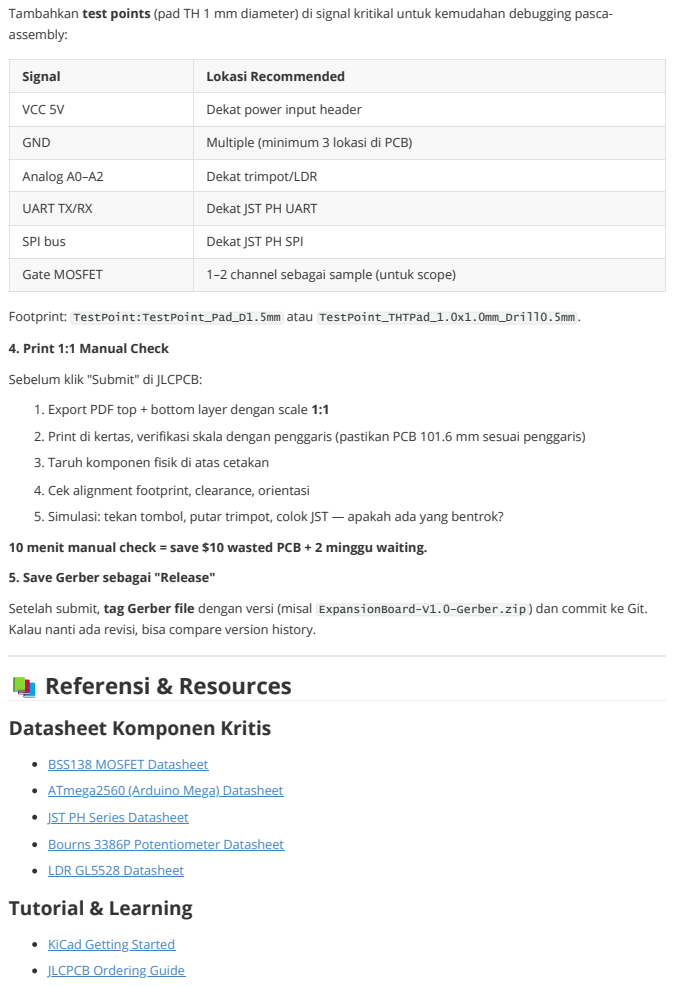
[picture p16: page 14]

Tambahkan test points (pad TH 1 mm diameter) di signal kritikal untuk kemudahan debugging pasca-
assembly:

Signal | Lokasi Recommended

VCC 5V | Dekat power input header

GND | Multiple (minimum 3 lokasi di PCB)

Analog A0–A2 | Dekat trimpot/LDR

UART TX/RX | Dekat JST PH UART

SPI bus | Dekat JST PH SPI

Gate MOSFET | 1–2 channel sebagai sample (untuk scope)

Footprint: TestPoint:TestPoint_Pad_D1.5mm atau TestPoint_THTPad_1.0x1.0mm_Drill0.5mm .
4. Print 1:1 Manual Check
Sebelum klik "Submit" di JLCPCB:
1. Export PDF top + bottom layer dengan scale 1:1
2. Print di kertas, verifikasi skala dengan penggaris (pastikan PCB 101.6 mm sesuai penggaris)
3. Taruh komponen fisik di atas cetakan
4. Cek alignment footprint, clearance, orientasi
5. Simulasi: tekan tombol, putar trimpot, colok JST — apakah ada yang bentrok?
10 menit manual check = save $10 wasted PCB + 2 minggu waiting.
5. Save Gerber sebagai "Release"
Setelah submit, tag Gerber file dengan versi (misal ExpansionBoard-V1.0-Gerber.zip ) dan commit ke Git.
Kalau nanti ada revisi, bisa compare version history.
📚 Referensi & Resources
Datasheet Komponen Kritis

BSS138 MOSFET Datasheet (https://www.onsemi.com/pdf/datasheet/bss138-d.pdf)
ATmega2560 (Arduino Mega) Datasheet (https://ww1.microchip.com/downloads/en/DeviceDoc/ATmega640-1280-1281-2560-2561-Datasheet-DS40002211A.pdf)
JST PH Series Datasheet (https://www.jst-mfg.com/product/pdf/eng/ePH.pdf)
Bourns 3386P Potentiometer Datasheet (https://www.bourns.com/docs/product-datasheets/3386.pdf)
LDR GL5528 Datasheet (https://akizukidenshi.com/download/ds/senba/GL55%20Series%20Photoresistor.pdf)
Tutorial & Learning

KiCad Getting Started (https://docs.kicad.org/)
JLCPCB Ordering Guide (https://jlcpcb.com/help)

## Inspirasi Desain

Cytron Maker Pi Pico Schematic (https://www.cytron.io/c-expansion-for-raspberry-pi-pico/p-maker-pi-pico-simplifying-raspberry-pi-pico-for-beginners-and-kits) — referensi MOSFET isolation topology Arduino Mega R3 Schematic (https://www.arduino.cc/en/uploads/Main/arduino-mega2560-schematic.pdf)

## Library KiCad

SnapEDA Arduino Mega 2560 Rev3 (https://www.snapeda.com/parts/ARDUINO%20MEGA%202560%20REV3%20%7C%20A000067/Arduino/view-part/)

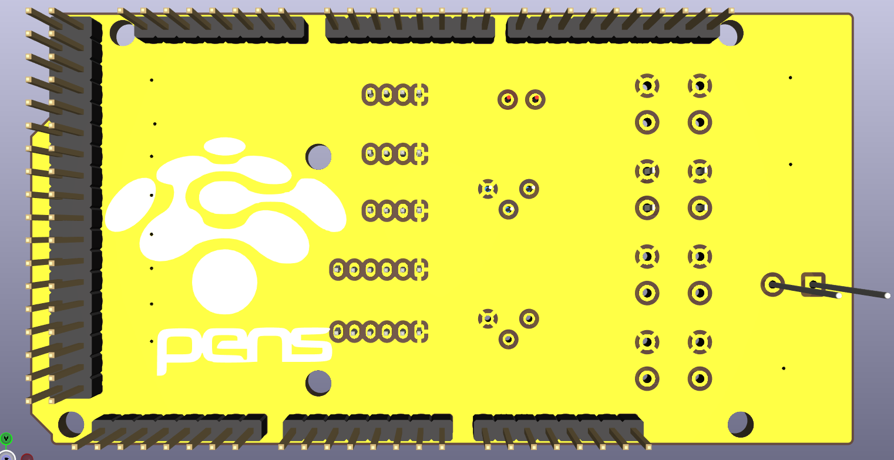
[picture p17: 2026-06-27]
VersiB/PCB2.png

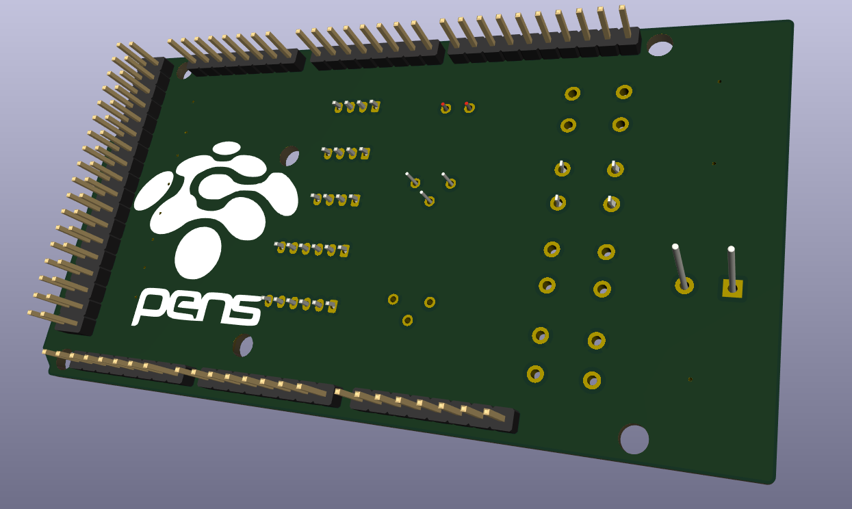
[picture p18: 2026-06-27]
VersiB/PCB3.png

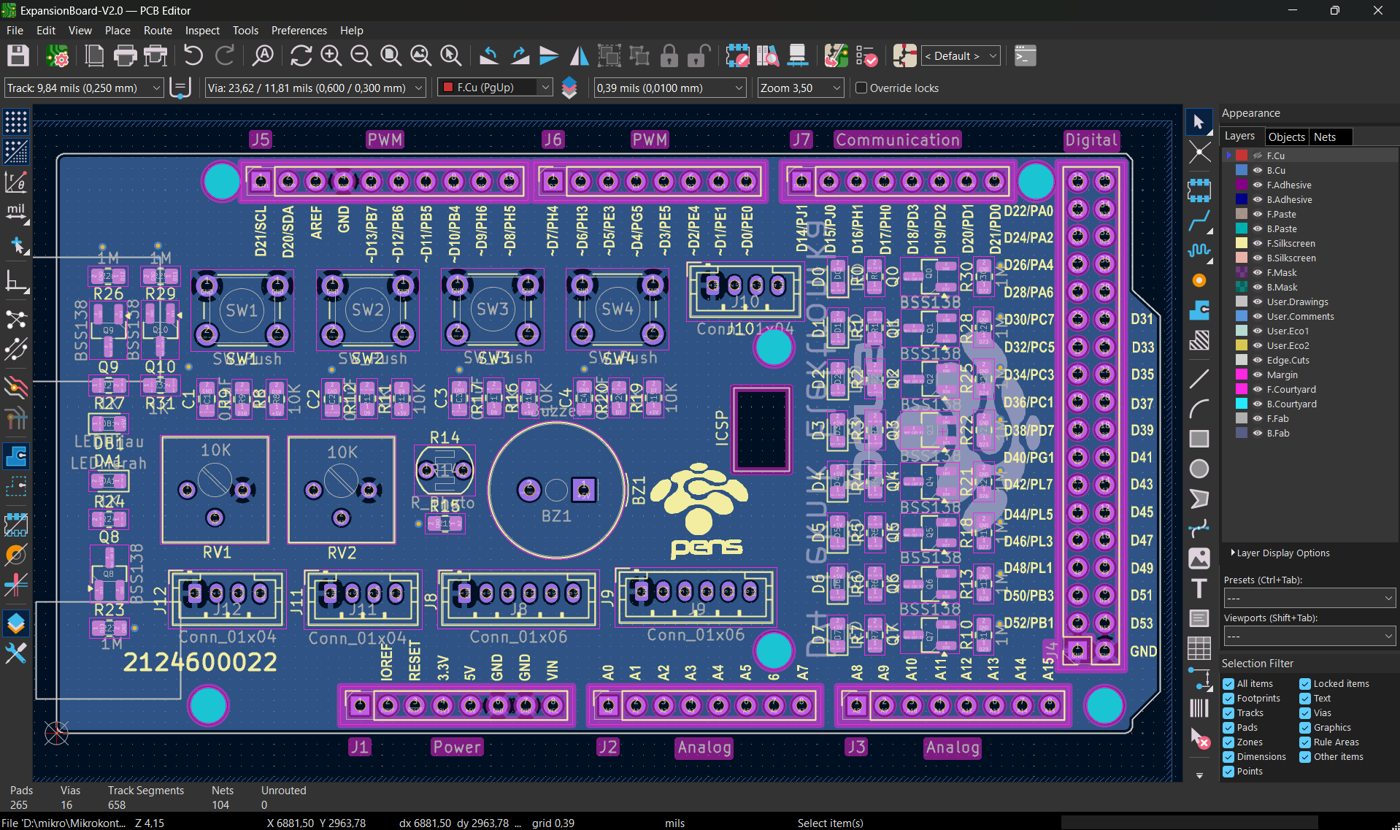
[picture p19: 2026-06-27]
versiA/Bottom.png

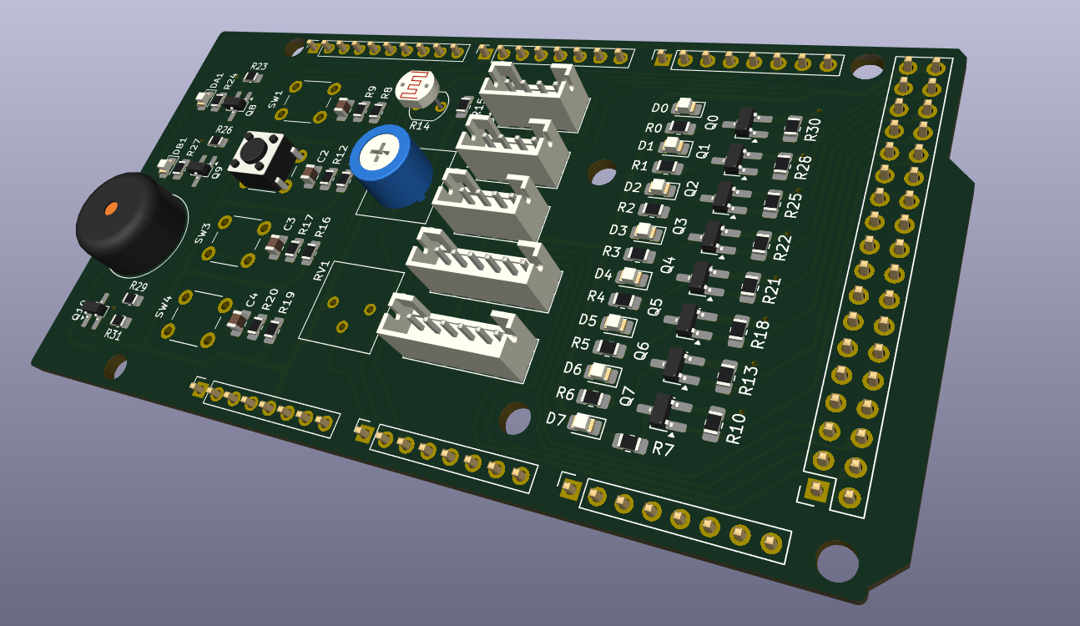
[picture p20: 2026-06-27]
VersiB/PCB4.png

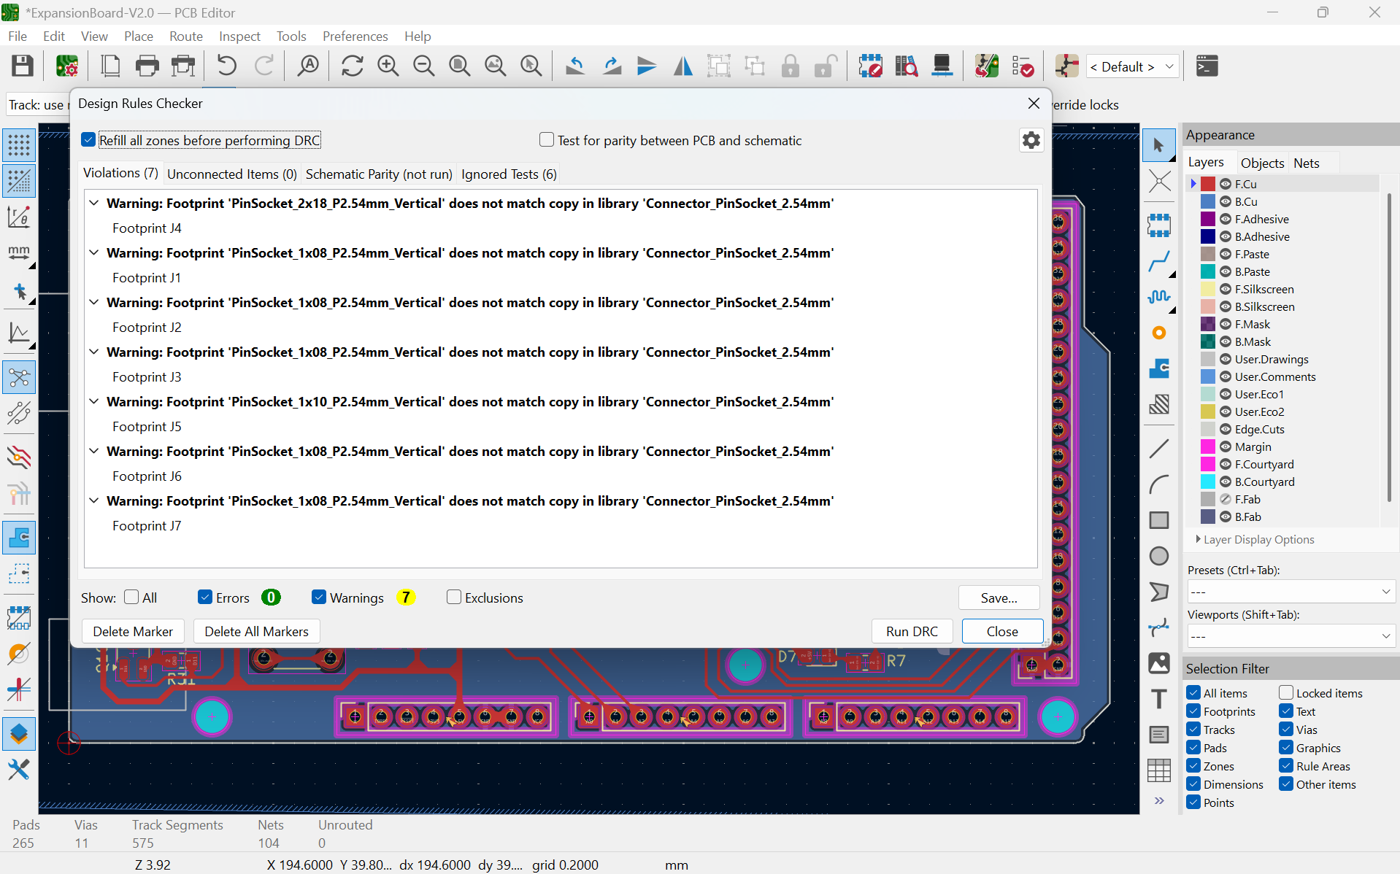
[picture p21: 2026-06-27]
VersiB/DRC.png

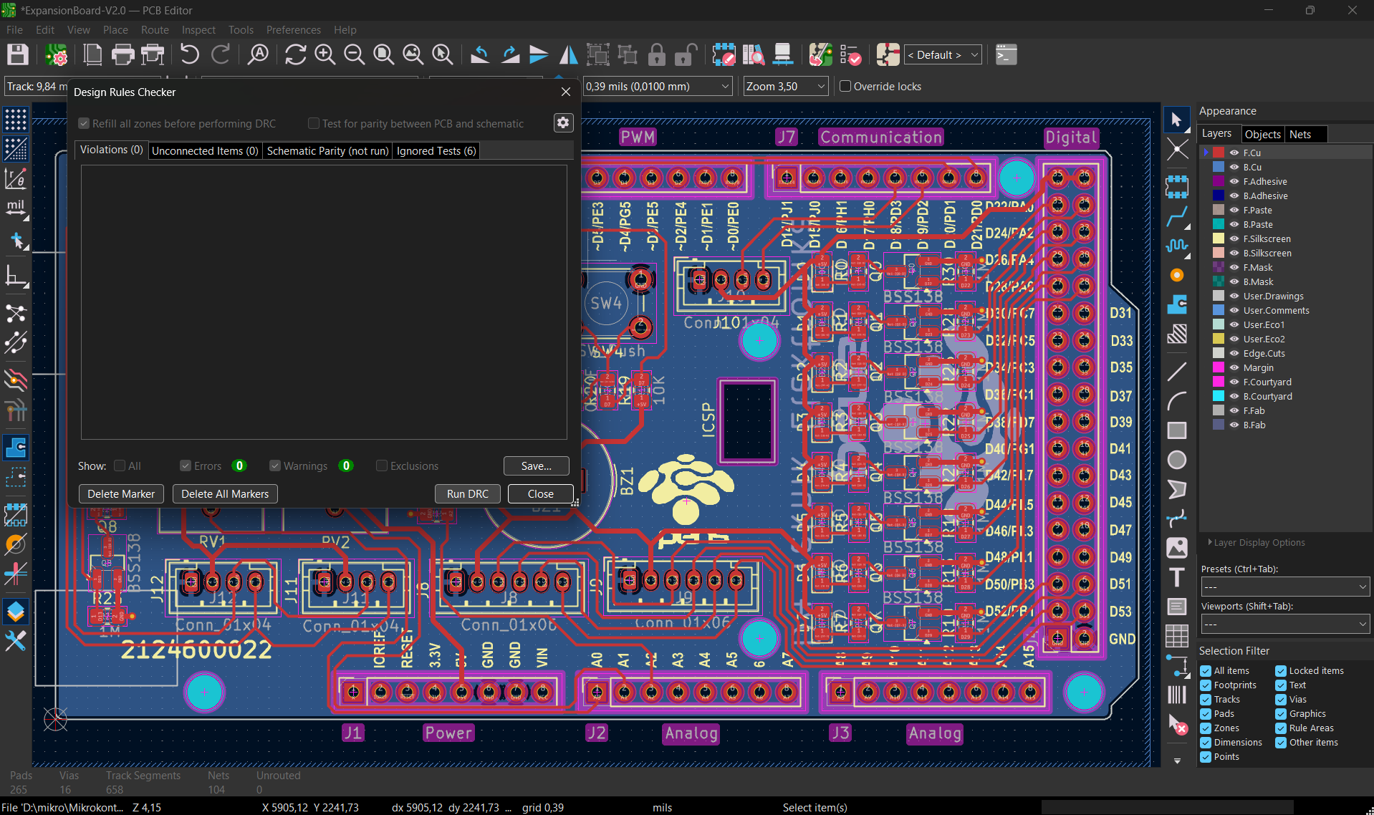
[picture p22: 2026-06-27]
versiA/Warning dan Error.png

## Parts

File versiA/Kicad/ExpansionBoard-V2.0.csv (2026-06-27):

Reference | Value | Datasheet | Footprint | Qty | DNP
BZ1 | Buzzer |  |  | 1
C1,C2,C3,C4 | 0.1uF |  | Capacitor_SMD:C_0805_2012Metric_Pad1.18x1.45mm_HandSolder | 4
D0,D1,D2,D3,D4,D5,D6,D7 | LED |  | LED_SMD:LED_0805_2012Metric_Pad1.15x1.40mm_HandSolder | 8
DA1 | LEDMerah |  | LED_SMD:LED_0805_2012Metric_Pad1.15x1.40mm_HandSolder | 1
DB1 | LEDHijau |  | LED_SMD:LED_0805_2012Metric_Pad1.15x1.40mm_HandSolder | 1
J1 | Power |  | Connector_PinSocket_2.54mm:PinSocket_1x08_P2.54mm_Vertical | 1
J2,J3 | Analog |  | Connector_PinSocket_2.54mm:PinSocket_1x08_P2.54mm_Vertical | 2
J4 | Digital |  | Connector_PinSocket_2.54mm:PinSocket_2x18_P2.54mm_Vertical | 1
J5,J6 | PWM |  | Connector_PinSocket_2.54mm:PinSocket_1x08_P2.54mm_Vertical,Connector_PinSocket_2.54mm:PinSocket_1x10_P2.54mm_Vertical | 2
J7 | Communication |  | Connector_PinSocket_2.54mm:PinSocket_1x08_P2.54mm_Vertical | 1
J8,J9 | Conn_01x06 |  | Connector_JST:JST_PH_B6B-PH-K_1x06_P2.00mm_Vertical | 2
J10,J11,J12 | Conn_01x04 |  | Connector_JST:JST_PH_B4B-PH-K_1x04_P2.00mm_Vertical | 3
Q0,Q1,Q2,Q3,Q4,Q5,Q6,Q7,Q8,Q9,Q10 | BSS138 | https://www.onsemi.com/pub/Collateral/BSS138-D.PDF | Package_TO_SOT_SMD:SOT-23_Handsoldering | 11
R0,R1,R2,R3,R4,R5,R6,R7,R9,R12,R17,R20,R24,R27,R31 | 1K |  | Resistor_SMD:R_0805_2012Metric_Pad1.20x1.40mm_HandSolder | 15
R8,R11,R15,R16,R19,RV1,RV2 | 10K |  | Potentiometer_THT:Potentiometer_Bourns_3386P_Vertical,Resistor_SMD:R_0805_2012Metric_Pad1.20x1.40mm_HandSolder | 7
R10,R13,R18,R21,R22,R23,R25,R26,R28,R29,R30 | 1M |  | Resistor_SMD:R_0805_2012Metric_Pad1.20x1.40mm_HandSolder | 11
R14 | R_Photo |  | OptoDevice:R_LDR_5.1x4.3mm_P3.4mm_Vertical | 1
SW1,SW2,SW3,SW4 | SW_Push |  | Button_Switch_THT:SW_PUSH_6mm,SW_PUSH_6mm | 4

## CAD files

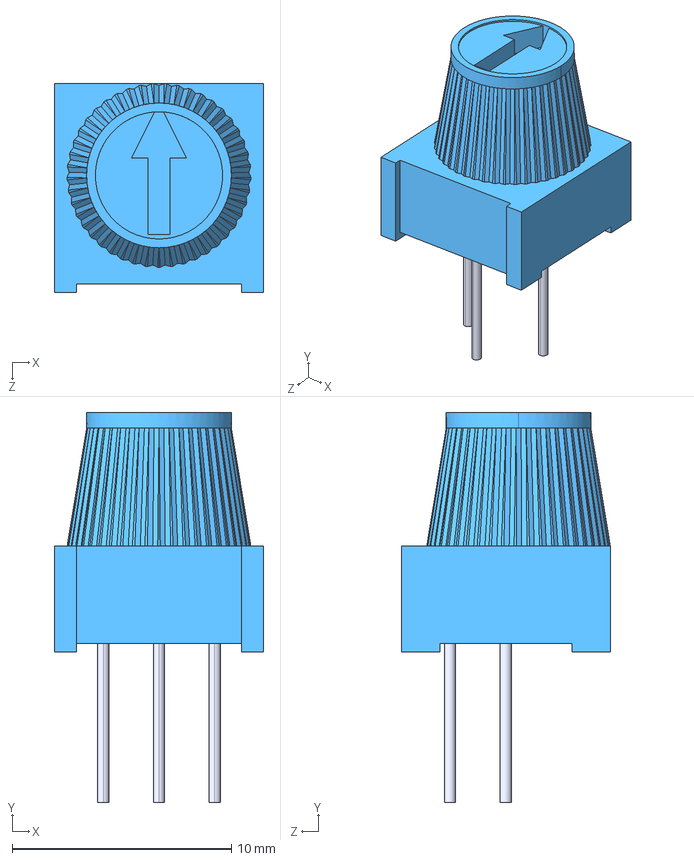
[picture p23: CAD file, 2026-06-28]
versiA/Kicad/3386P-1-104TLF.STEP
9.53 x 17.8 x 9.53 mm

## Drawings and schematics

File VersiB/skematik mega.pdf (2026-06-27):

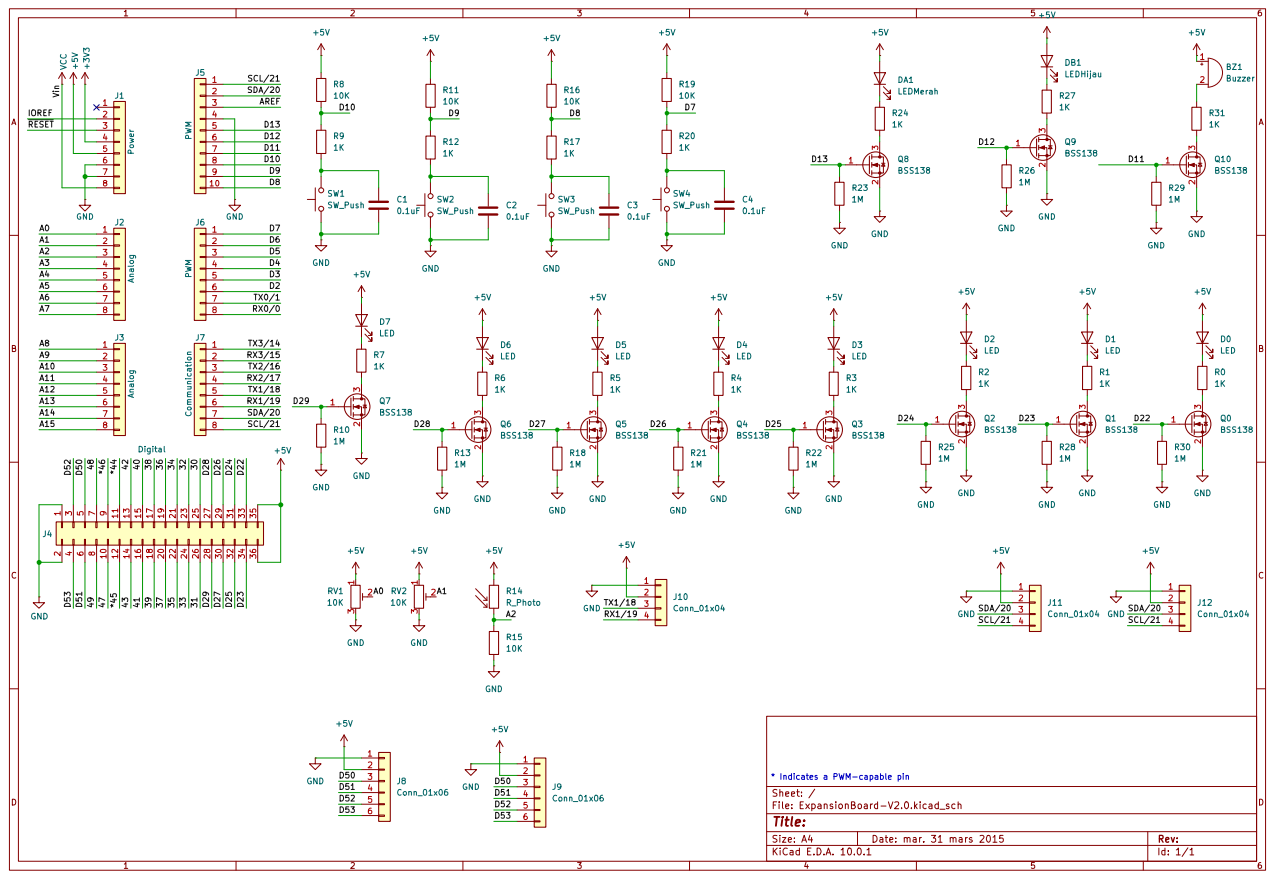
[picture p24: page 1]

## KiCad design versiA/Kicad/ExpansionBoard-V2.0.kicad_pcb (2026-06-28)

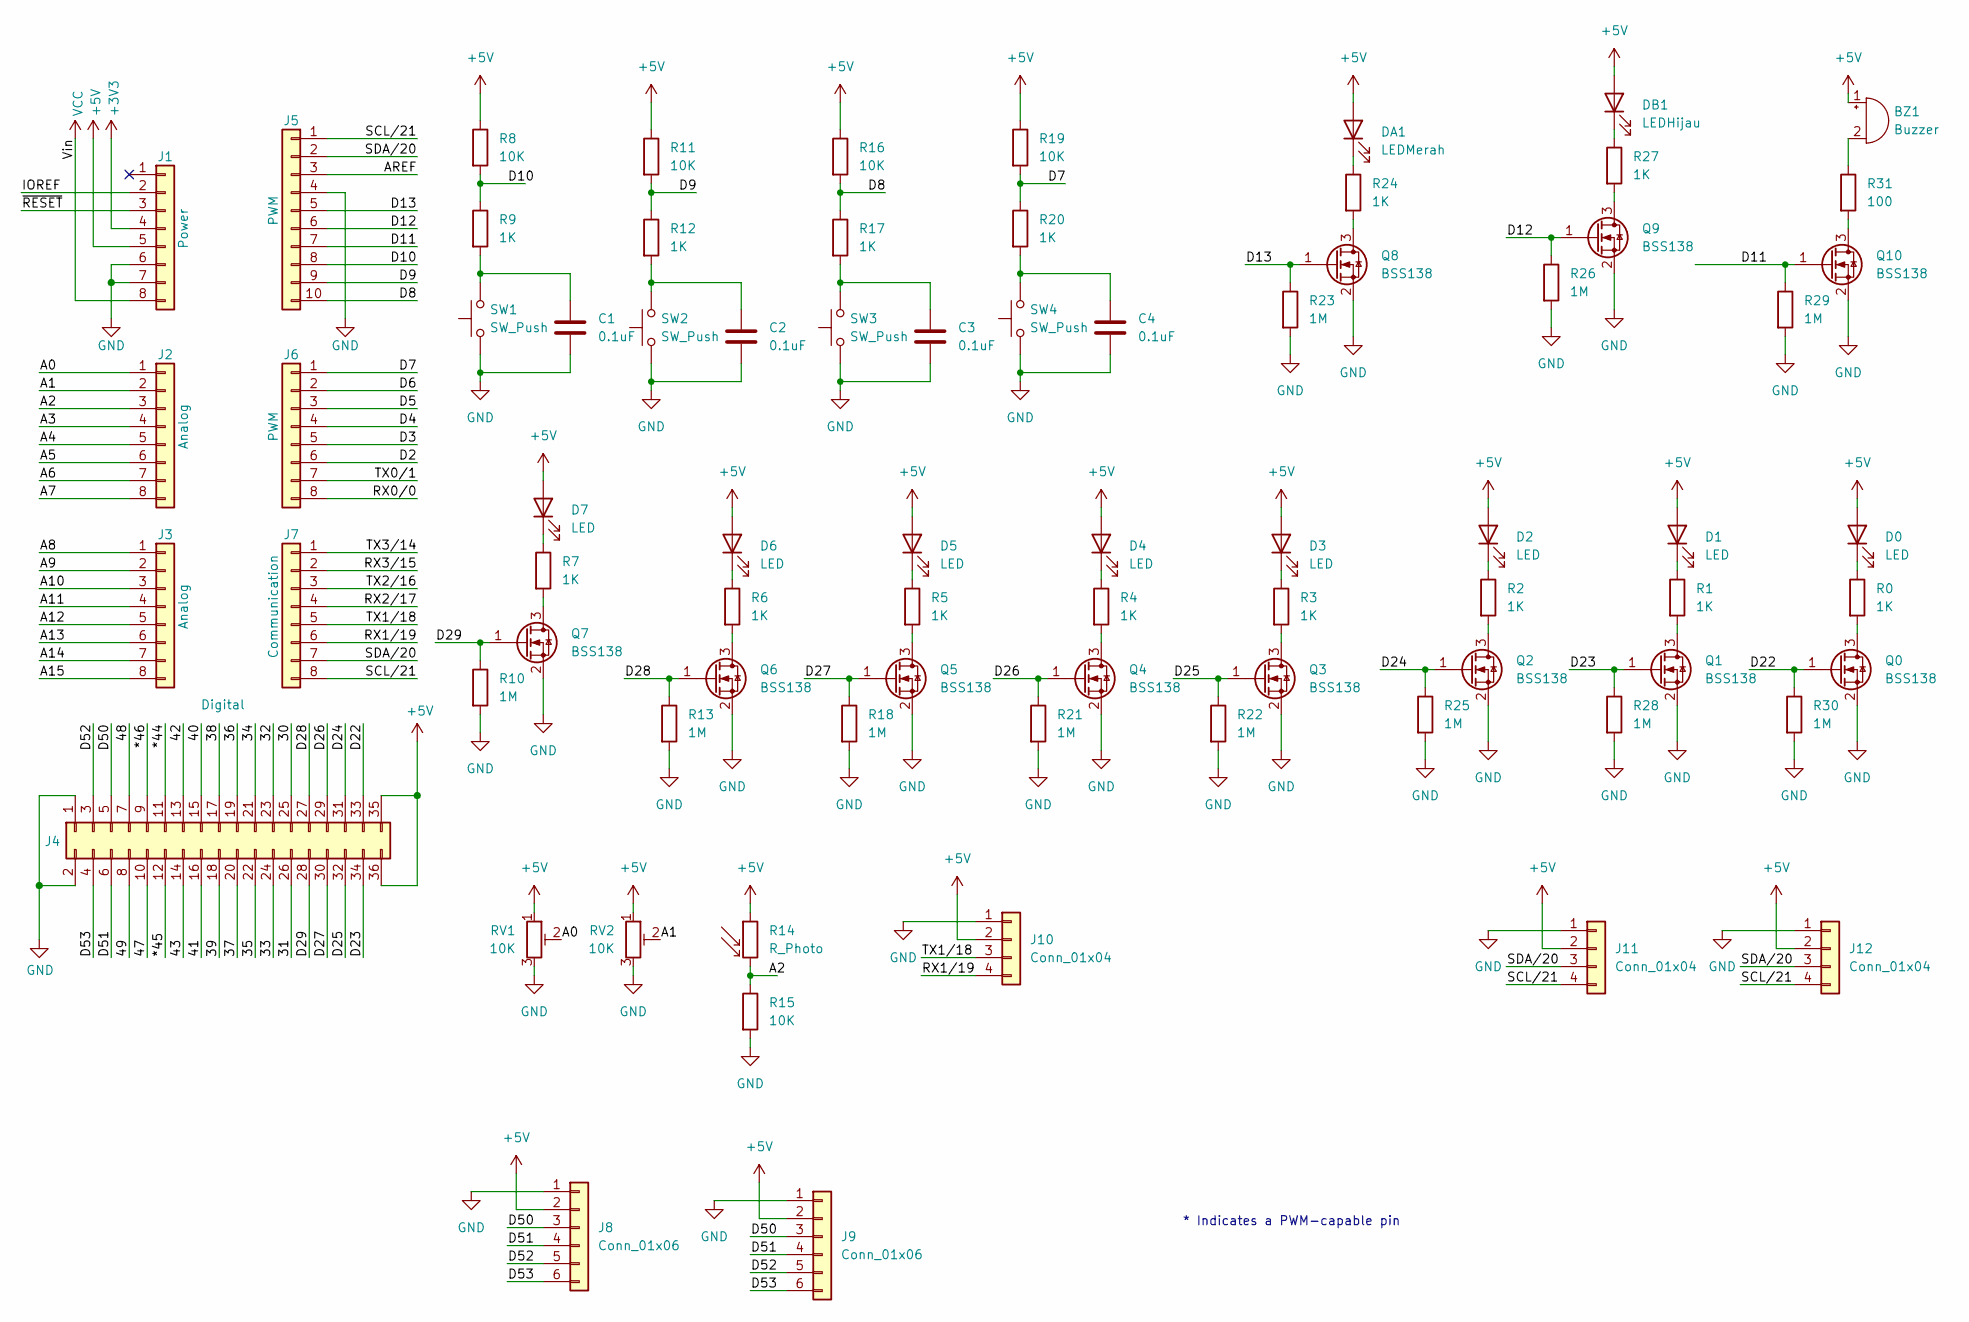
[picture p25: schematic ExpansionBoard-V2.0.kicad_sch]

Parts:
BZ1: Buzzer; Buzzer_TDK_PS1240P02BT_D12.2mm_H6.5mm
C1, C2, C3, C4: 0.1uF; C_0805_2012Metric_Pad1.18x1.45mm_HandSolder
D0, D1, D2, D3, D4, D5, D6, D7: LED; LED_0805_2012Metric_Pad1.15x1.40mm_HandSolder
DA1: LEDMerah; LED_0805_2012Metric_Pad1.15x1.40mm_HandSolder
DB1: LEDHijau; LED_0805_2012Metric_Pad1.15x1.40mm_HandSolder
J1: Power; PinSocket_1x08_P2.54mm_Vertical
J2, J3: Analog; PinSocket_1x08_P2.54mm_Vertical
J4: Digital; PinSocket_2x18_P2.54mm_Vertical
J5: PWM; PinSocket_1x10_P2.54mm_Vertical
J6: PWM; PinSocket_1x08_P2.54mm_Vertical
J7: Communication; PinSocket_1x08_P2.54mm_Vertical
J8, J9: Conn_01x06; JST_PH_B6B-PH-K_1x06_P2.00mm_Vertical
J10, J11, J12: Conn_01x04; JST_PH_B4B-PH-K_1x04_P2.00mm_Vertical
Q0, Q1, Q2, Q3, Q4, Q5, Q6, Q7, Q8, Q9, Q10: BSS138; SOT-23_Handsoldering
R0, R1, R2, R3, R4, R5, R6, R7, R9, R12, R17, R20, R24, R27: 1K; R_0805_2012Metric_Pad1.20x1.40mm_HandSolder
R8, R11, R15, R16, R19: 10K; R_0805_2012Metric_Pad1.20x1.40mm_HandSolder
R10, R13, R18, R21, R22, R23, R25, R26, R28, R29, R30: 1M; R_0805_2012Metric_Pad1.20x1.40mm_HandSolder
R14: R_Photo; R_LDR_5.1x4.3mm_P3.4mm_Vertical
R31: 100; R_0805_2012Metric_Pad1.20x1.40mm_HandSolder
RV1, RV2: 10K; Potentiometer_Bourns_3386P_Vertical
SW1, SW2, SW3, SW4: SW_Push; SW_PUSH_6mm

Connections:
+3V3: J1.4
+5V: BZ1.1 (+), D0.2 (A), D1.2 (A), D2.2 (A), D3.2 (A), D4.2 (A), D5.2 (A), D6.2 (A), D7.2 (A), DA1.2 (A), DB1.2 (A), J1.5, J4.35, J4.36, J8.2, J9.2, J10.2, J11.2, J12.2, R8.1, R11.1, R14.1, R16.1, R19.1, RV1.1, RV2.1
/30: J4.25
/31: J4.26
/32: J4.23
/33: J4.24
/34: J4.21
/35: J4.22
/36: J4.19
/37: J4.20
/38: J4.17
/39: J4.18
/40: J4.15
/41: J4.16
/42: J4.13
/43: J4.14
/47: J4.10
/48: J4.7
/49: J4.8
/*44: J4.11
/*45: J4.12
/*46: J4.9
/A0: J2.1, RV1.2
/A1: J2.2, RV2.2
/A2: J2.3, R14.2, R15.1
/A3: J2.4
/A4: J2.5
/A5: J2.6
/A6: J2.7
/A7: J2.8
/A8: J3.1
/A9: J3.2
/A10: J3.3
/A11: J3.4
/A12: J3.5
/A13: J3.6
/A14: J3.7
/A15: J3.8
/AREF: J5.3
/D2: J6.6
/D3: J6.5
/D4: J6.4
/D5: J6.3
/D6: J6.2
/D7: J6.1, R19.2, R20.1
/D8: J5.10, R16.2, R17.1
/D9: J5.9, R11.2, R12.1
/D10: J5.8, R8.2, R9.1
/D11: J5.7, Q10.1 (G), R29.1
/D12: J5.6, Q9.1 (G), R26.1
/D13: J5.5, Q8.1 (G), R23.1
/D22: J4.33, Q0.1 (G), R30.1
/D23: J4.34, Q1.1 (G), R28.1
/D24: J4.31, Q2.1 (G), R25.1
/D25: J4.32, Q3.1 (G), R22.1
/D26: J4.29, Q4.1 (G), R21.1
/D27: J4.30, Q5.1 (G), R18.1
/D28: J4.27, Q6.1 (G), R13.1
/D29: J4.28, Q7.1 (G), R10.1
/D50: J4.5, J8.3, J9.3
/D51: J4.6, J8.4, J9.4
/D52: J4.3, J8.5, J9.5
/D53: J4.4, J8.6, J9.6
/IOREF: J1.2
/RX0/0: J6.8
/RX1/19: J7.6, J10.4
/RX2/17: J7.4
/RX3/15: J7.2
/SCL/21: J5.1, J7.8, J11.4, J12.4
/SDA/20: J5.2, J7.7, J11.3, J12.3
/TX0/1: J6.7
/TX1/18: J7.5, J10.3
/TX2/16: J7.3
/TX3/14: J7.1
/~RESET: J1.3
GND: C1.2, C2.2, C3.2, C4.2, J1.6, J1.7, J4.1, J4.2, J5.4, J8.1, J9.1, J10.1, J11.1, J12.1, Q0.2 (S), Q1.2 (S), Q2.2 (S), Q3.2 (S), Q4.2 (S), Q5.2 (S), Q6.2 (S), Q7.2 (S), Q8.2 (S), Q9.2 (S), Q10.2 (S), R10.2, R13.2, R15.2, R18.2, R21.2, R22.2, R23.2, R25.2, R26.2, R28.2, R29.2, R30.2, RV1.3, RV2.3, SW1.1, SW2.1, SW3.1, SW4.1
unnamed: BZ1.2 (-), R31.1
unnamed: C1.1, R9.2, SW1.2
unnamed: C2.1, R12.2, SW2.2
unnamed: C3.1, R17.2, SW3.2
unnamed: C4.1, R20.2, SW4.2
unnamed: D0.1 (K), R0.1
unnamed: D1.1 (K), R1.1
unnamed: D2.1 (K), R2.1
unnamed: D3.1 (K), R3.1
unnamed: D4.1 (K), R4.1
unnamed: D5.1 (K), R5.1
unnamed: D6.1 (K), R6.1
unnamed: D7.1 (K), R7.1
unnamed: DA1.1 (K), R24.1
unnamed: DB1.1 (K), R27.1
unnamed: Q0.3 (D), R0.2
unnamed: Q1.3 (D), R1.2
unnamed: Q2.3 (D), R2.2
unnamed: Q3.3 (D), R3.2
unnamed: Q4.3 (D), R4.2
unnamed: Q5.3 (D), R5.2
unnamed: Q6.3 (D), R6.2
unnamed: Q7.3 (D), R7.2
unnamed: Q8.3 (D), R24.2
unnamed: Q9.3 (D), R27.2
unnamed: Q10.3 (D), R31.2
VCC: J1.8

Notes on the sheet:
* Indicates a PWM-capable pin

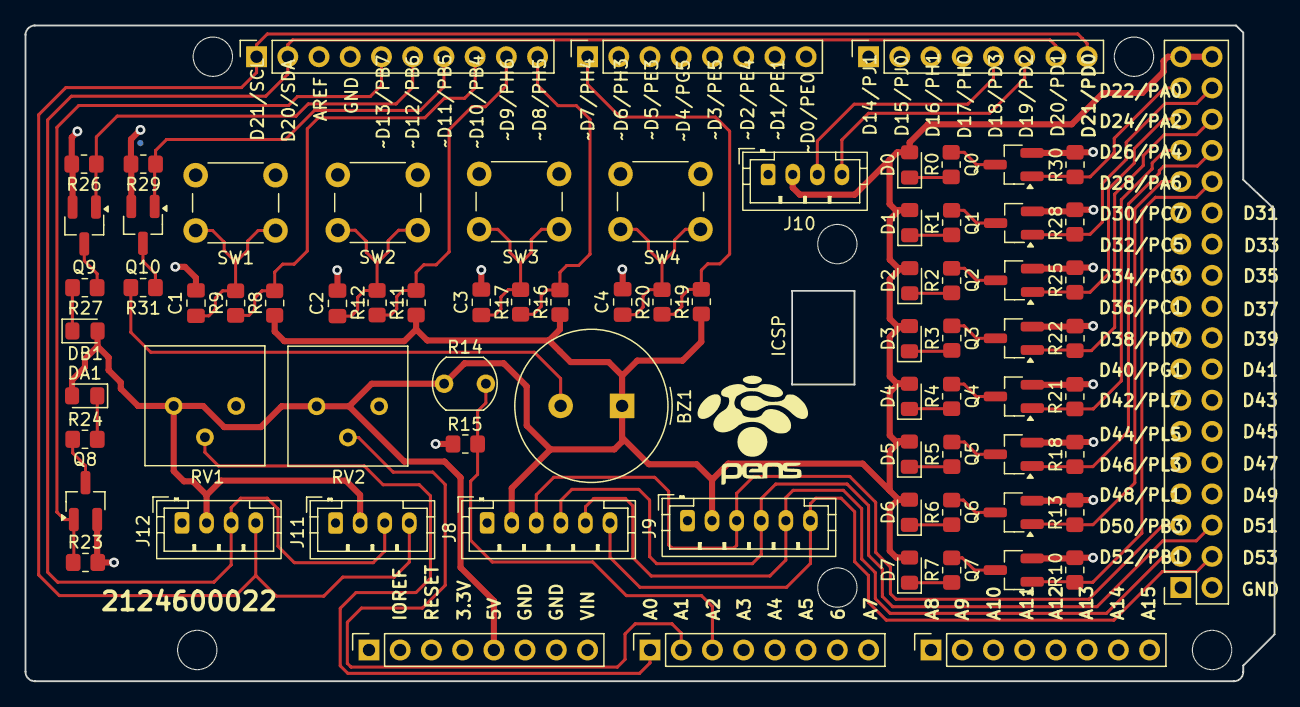
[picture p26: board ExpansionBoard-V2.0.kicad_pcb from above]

Board: 2 copper layers, 101.6 x 53.3 mm, 82 parts (0 on the bottom side), 54 nets.

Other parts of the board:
MH1, MH2, MH3, MH4, MH5, MH6: MountingHole_3.2mm

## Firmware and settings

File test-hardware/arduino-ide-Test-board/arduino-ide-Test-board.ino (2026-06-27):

/*
   PENS Expansion Board V2.0
   Full Hardware Test
   Arduino Mega 2560
*/

// =======================
// LED ARRAY
// =======================
const byte leds[] = {
  22, 23, 24, 25,
  26, 27, 28, 29
};

// =======================
// LED INDIKATOR
// =======================
#define LED_RED   12
#define LED_GREEN 13

// =======================
// BUZZER PASIF
// =======================
#define BUZZER 11

// =======================
// BUTTON
// =======================
#define BTN1 10
#define BTN2 9
#define BTN3 8
#define BTN4 7

// =======================
// ANALOG
// =======================
#define POT1 A0
#define POT2 A1
#define LDR  A2

// =================================================
// BUZZER TEST
// =================================================
void testBuzzer()
{
  Serial.println("=== BUZZER TEST ===");

  int melody[] = {
    262, 294, 330, 349,
    392, 440, 494, 523
  };

  for (int i = 0; i < 8; i++) {
    tone(BUZZER, melody[i]);
    delay(200);
  }

  noTone(BUZZER);
  delay(300);
}

// =================================================
// LED TEST
// =================================================
void testLED()
{
  Serial.println("=== LED TEST ===");

  for (int i = 0; i < 8; i++) {
    digitalWrite(leds[i], HIGH);
    delay(100);
    digitalWrite(leds[i], LOW);
  }

  digitalWrite(LED_RED, HIGH);
  delay(300);
  digitalWrite(LED_RED, LOW);

  digitalWrite(LED_GREEN, HIGH);
  delay(300);
  digitalWrite(LED_GREEN, LOW);
}

// =================================================
// PORTA COUNTER
// =================================================
void testCounter()
{
  Serial.println("=== PORTA COUNTER ===");

  for (int n = 0; n < 256; n++) {

    for (int b = 0; b < 8; b++) {
      digitalWrite(leds[b], bitRead(n, b));
    }

    delay(25);
  }

  for (int i = 0; i < 8; i++) {
    digitalWrite(leds[i], LOW);
  }
}

// =================================================
// BUTTON TEST
// =================================================
void testButton()
{
  Serial.println("=== BUTTON TEST ===");
  Serial.println("Tekan tombol selama 10 detik");

  unsigned long t0 = millis();

  while (millis() - t0 < 10000) {

    if (!digitalRead(BTN1)) {
      Serial.println("BTN1");
      tone(BUZZER, 500);
      digitalWrite(LED_RED, HIGH);
    }

    else if (!digitalRead(BTN2)) {
      Serial.println("BTN2");
      tone(BUZZER, 1000);
      digitalWrite(LED_GREEN, HIGH);
    }

    else if (!digitalRead(BTN3)) {
      Serial.println("BTN3");
      tone(BUZZER, 1500);

      for (int i = 0; i < 8; i++)
        digitalWrite(leds[i], HIGH);
    }

    else if (!digitalRead(BTN4)) {
      Serial.println("BTN4");
      tone(BUZZER, 2000);

      for (int i = 0; i < 8; i++)
        digitalWrite(leds[i], i & 1);
    }

    else {
      noTone(BUZZER);

      digitalWrite(LED_RED, LOW);
      digitalWrite(LED_GREEN, LOW);

      for (int i = 0; i < 8; i++)
        digitalWrite(leds[i], LOW);
    }

    delay(50);
  }

  noTone(BUZZER);
}

// =================================================
// ANALOG TEST
// =================================================
void testAnalog()
{
  Serial.println("=== ANALOG TEST ===");

  for (int i = 0; i < 30; i++) {

    int p1 = analogRead(POT1);
    int p2 = analogRead(POT2);
    int l  = analogRead(LDR);

    Serial.print("POT1=");
    Serial.print(p1);

    Serial.print("  POT2=");
    Serial.print(p2);

    Serial.print("  LDR=");
    Serial.println(l);

    delay(200);
  }
}

void setup()
{
  Serial.begin(115200);

  for (int i = 0; i < 8; i++) {
    pinMode(leds[i], OUTPUT);
  }

  pinMode(LED_RED, OUTPUT);
  pinMode(LED_GREEN, OUTPUT);

  pinMode(BUZZER, OUTPUT);

  pinMode(BTN1, INPUT_PULLUP);
  pinMode(BTN2, INPUT_PULLUP);
  pinMode(BTN3, INPUT_PULLUP);
  pinMode(BTN4, INPUT_PULLUP);

  delay(1000);

  Serial.println();
  Serial.println("PENS Expansion Board V2.0");
  Serial.println("Hardware Self Test");
}

void loop()
{
  testLED();

  testBuzzer();

  testButton();

  testAnalog();

  testCounter();

  Serial.println("===== TEST COMPLETE =====");
  delay(2000);
}
